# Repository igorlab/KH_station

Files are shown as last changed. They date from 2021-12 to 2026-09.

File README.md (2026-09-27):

# KH station




**An automatic KH tester for reef aquariums.** It takes a sample of tank water, titrates
it with acid on its own schedule, and sends the result to your Telegram. A live
dashboard runs in your browser, and every reading can also be logged to
[labaqua.net](https://labaqua.net/).

- Measures KH (carbonate hardness) by real titration to pH 4.10, no test kit or colour
  chart
- Runs on a schedule, rinses itself, and re-checks any result that looks off
- Controlled from Telegram, a web page on your network, or USB
- Updates its own firmware over Wi-Fi
- Open hardware: 3D-printed parts, ESP32 board, schematics and parts list in this repo

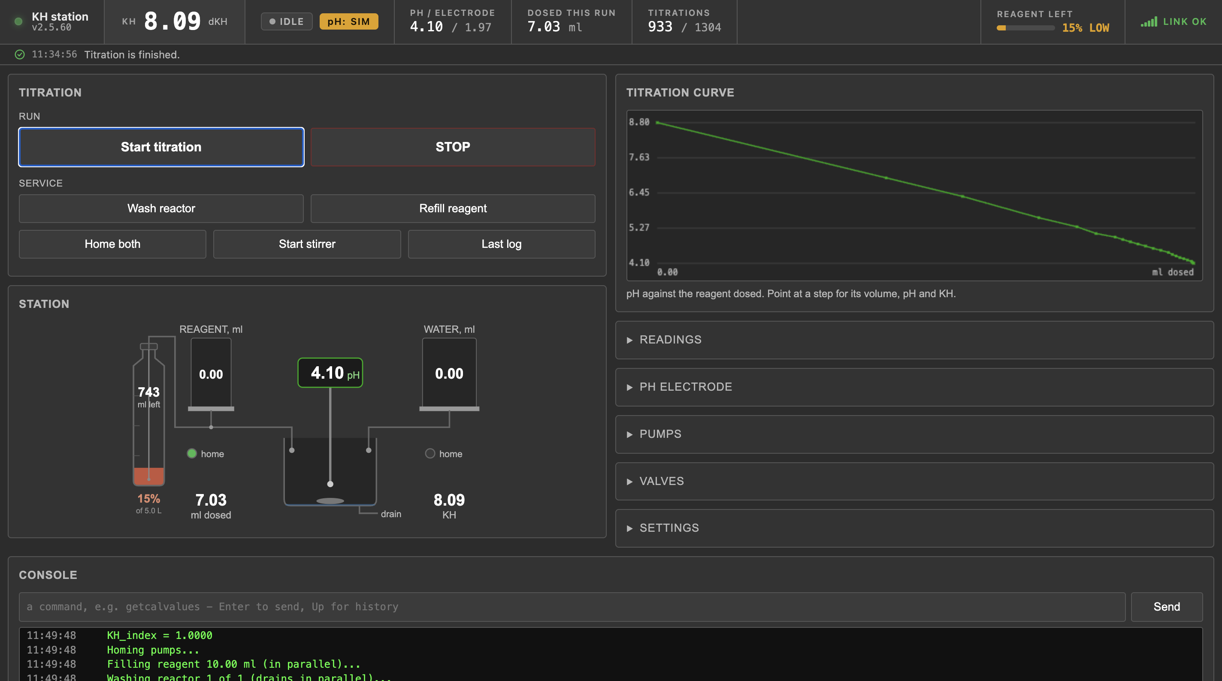
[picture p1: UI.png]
The KH station web dashboard
[](UI.png?raw=1)

*The web dashboard: latest KH, a live diagram of the station, the titration curve and
the console. Click for full size.*

<table>
<tr>
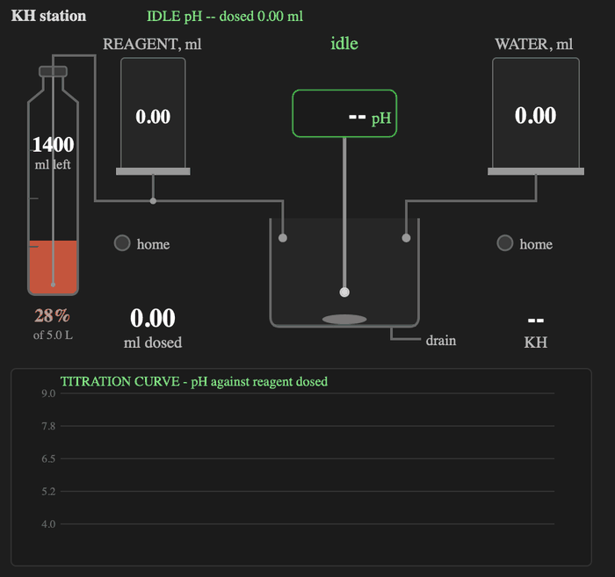
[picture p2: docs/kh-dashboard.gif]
A titration on the dashboard, start to finish
<td width="50%"></td>
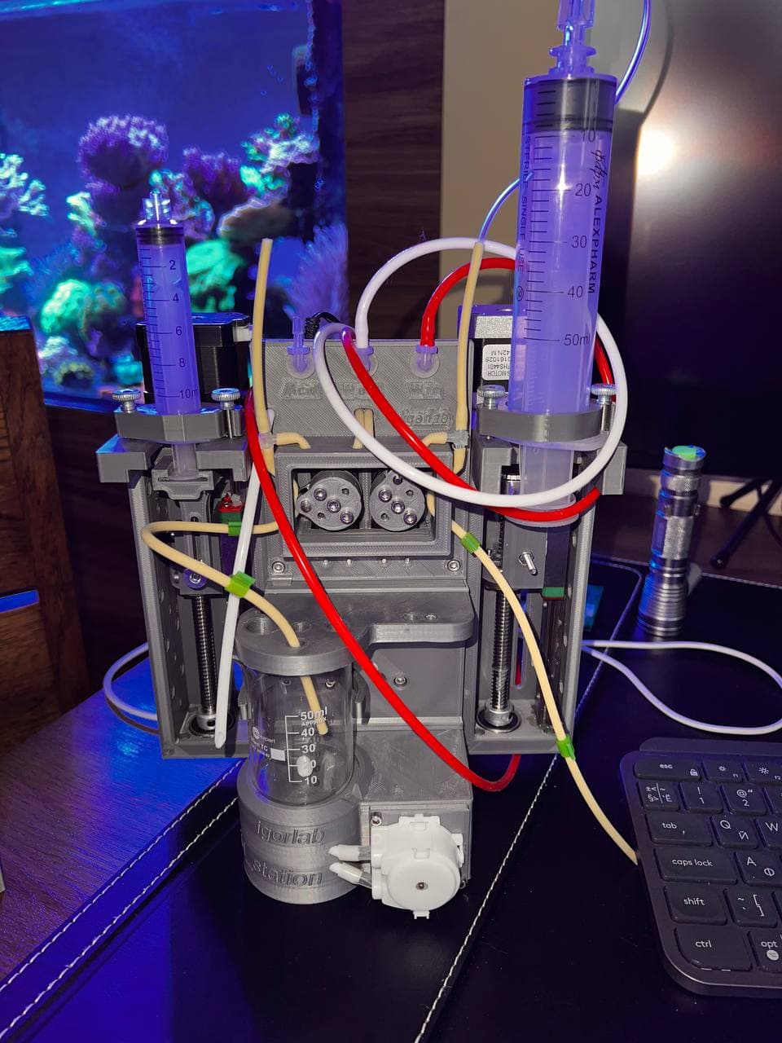
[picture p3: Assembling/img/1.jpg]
A built KH station next to a reef tank
<td width="50%"></td>
</tr>
<tr>
<td><em>One whole run on the dashboard, from rinse to result</em></td>
<td><em>A built station next to the tank</em></td>
</tr>
</table>

Build and demo video (https://youtu.be/T8ol2PM2Kjg)

Questions, feedback, or just want to see what other people are building? Join the
[Arduino Aquarium titrator group chat](https://t.me/+Ad4m-7L7tV1lNGNi).

**Contents:** [What it does](#what-it-does) ·
[Hardware](#hardware) ·
[Getting started](#getting-started) ·
[Web dashboard](#web-dashboard) ·
[Commands](#command-reference) ·
[Firmware updates](#firmware-updates) ·
[Building from source](#building-from-source)

---

## What it does

It runs a real titration — the same kind you'd do by hand with a syringe and a test kit
— except it does it by itself, on a timer, and tells you the number afterwards.

One run looks like this:

1. **Home** — both syringes move to their limit switches, so the machine knows exactly
   where they are before it starts.
2. **Draw reagent** — the reagent syringe pulls in 10 ml of HCl while the water side is
   busy with the next steps, so no time is wasted.
3. **Rinse** — the reactor gets flushed with tank water and drained, so nothing from the
   last test is left behind.
4. **Take a sample** — 25 ml of tank water goes into the reactor.
5. **Settle** — the stirrer runs for a bit so the electrode has time to give a steady
   reading.
6. **Dose** — acid goes in step by step, starting big (3 ml) and getting finer (down to
   0.01 ml) as the pH gets close to the endpoint. After each drop, it waits for the
   reading to actually settle instead of just waiting a fixed number of seconds.
7. **Endpoint** — dosing stops at **pH 4.10**.
8. **Wrap up** — both syringes go home, the reactor drains, and the result is sent out.

The math behind the number:

```
KH = (2804 × acid used, ml × acid concentration) / (sample size, ml / 1.026)
```

Defaults are 0.01 mol/L HCl and a 25 ml sample, both of which you can change.

If a result is more than `maxDeviation` (0.30 dKH by default) away from the last one,
the station doesn't just report it — it runs again to double-check. If two retries in a
row still don't agree, it tells you something's off instead of guessing.

---

## Hardware

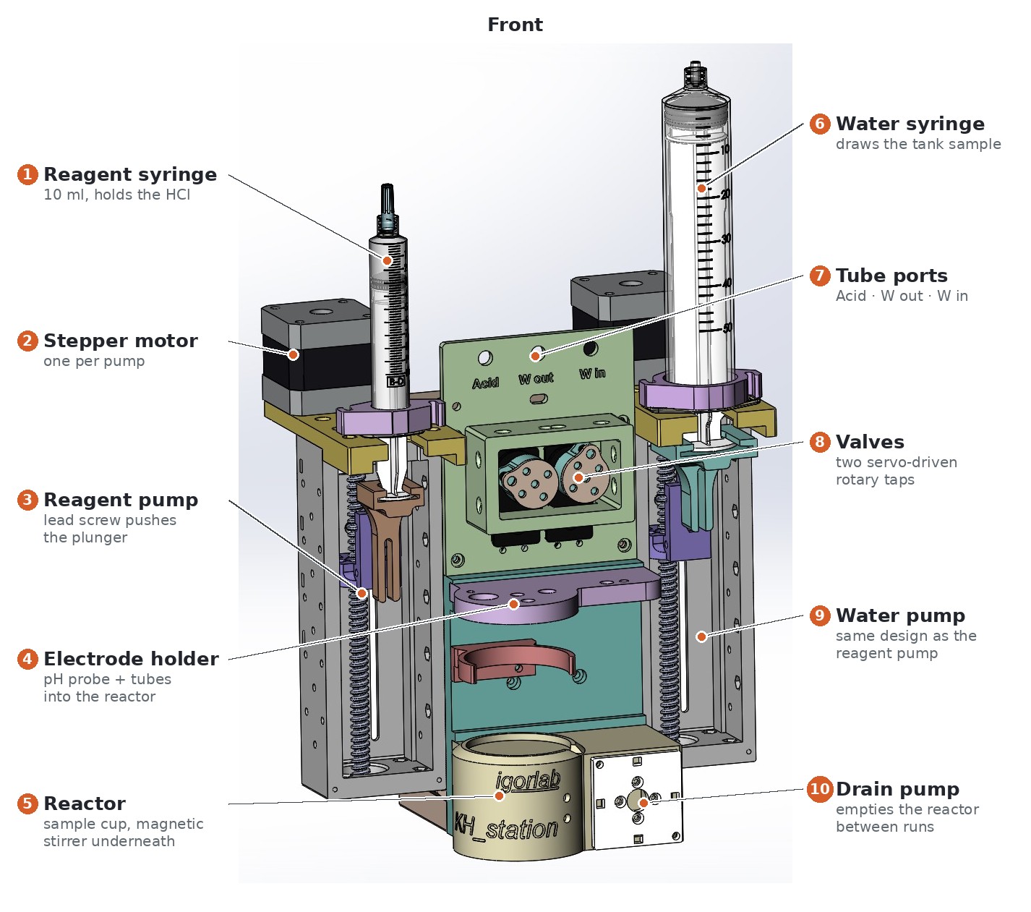
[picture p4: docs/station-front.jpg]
The station from the front, with its parts labelled


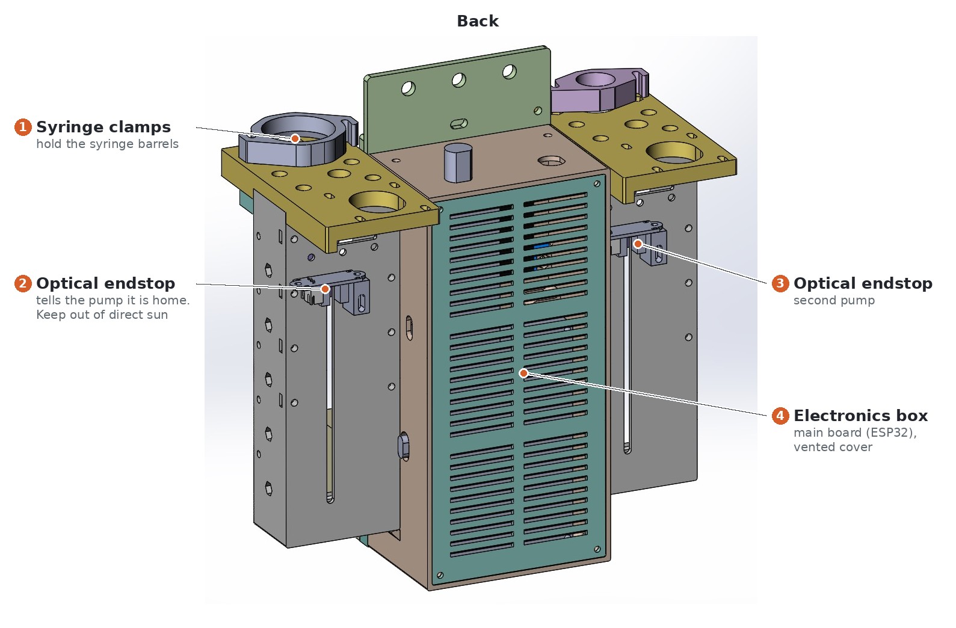
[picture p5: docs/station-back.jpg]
The station from the back, with its parts labelled


Full build guide with photos: [Assembling](Assembling/readme.md). Printed parts:
[STL](STL/). Board: [PCB](PCB/).

- **ESP32** (DOIT DEVKIT V1 or similar, 4 MB flash)
- **Two syringe pumps** — one for reagent (10 ml), one for the water sample (25 ml).
  Each has its own stepper motor, a limit switch for homing, and a small servo-driven
  valve that switches between filling and injecting.
- **pH electrode**, read through an amplifier board into the ESP32's ADC
- **Magnetic stirrer**
- **Drain pump** to empty the reactor between runs

Pin map (`include/PIN_definition.h`):

| Function | GPIO | | Function | GPIO |
|---|---|---|---|---|
| Reagent EN / STEP / DIR | 13 / 12 / 23 | | Water EN / STEP / DIR | 27 / 26 / 19 |
| Reagent endstop / valve | 16 / 18 | | Water endstop / valve | 5 / 17 |
| pH input | 35 | | pH loopback for bench testing | 25 |
| Drain pump | 33 | | Stirrer | 32 |
| Buzzer | 4 | | | |

### Pump speed

The two pumps don't all move at the same speed — on purpose:

| Move | Speed | Why it's set this way |
|---|---|---|
| Dosing | 1000 Hz | This is the number that becomes your KH result, so it moves carefully |
| Filling | 1500 Hz | Also matters for accuracy, but less critical, so a bit faster |
| Homing | 3000 Hz | Just driving to a limit switch, so it can go fast |

You can change any of these later (`setdosehz_`, `setfillhz_`, `sethomehz_`) if you've
tested your build at a higher speed and trust it.

### Keep the endstops out of the sun

The limit switches are **optical** (a light beam across a slot). Direct sunlight, or a
bright lamp shining into the slot, blinds them: the station then cannot tell that a
syringe has reached home, and homing fails or ends in an error. This has happened on a
real station. Place the station out of direct sun, or shade the endstops, keeping the
slot itself clear for the flag that moves through it.
If you see `Home can not be reached` or `endstop reads HOME but ... steps are still
loaded` in the console, check the light on the endstops first.

---

## Getting started

### 1. Set up the device

**Wi-Fi first.** On its first start the station opens its own Wi-Fi access point called
**AutoConnectAP**. Join it from your phone, pick your network and type its password —
the station remembers it and connects from then on. (It opens AutoConnectAP again
whenever it can't reach that network at startup — but since firmware 2.5.6 it no longer
waits there: it keeps titrating, looks for its network every minute and reconnects by
itself, so after a power cut it comes back even if the router starts slower than it.)

**Then Telegram.** You need a bot of your own and your numeric Telegram ID —
**[Setting up Telegram](docs/telegram-setup.md)** walks you through both in about five
minutes.

With those in hand, give it the rest — either on the page
`http://kh-station.local/settings` (linked at the bottom of the dashboard; it shows what
is already set), or over USB with a serial monitor at **115200 baud**,
one line at a time:

```
bottoken_<the token @BotFather gave you>
settlgrmid_<your numeric Telegram id>
ukey_<the token labaqua.net emailed you>
```

`ukey_` restarts the station, so send it last. Don't skip `settlgrmid_` — it's what
keeps strangers from being able to control your station over Telegram. If everything
went through, the bot will say "KH station started" once it restarts. Since firmware
2.5.13 that message also says **why** the station restarted — power cut, a dip in the
power supply, a crash or a command — and `lastreset` repeats it. If your station keeps
restarting on its own, that line is the thing to send when you ask for help. Bot
silent? See [If the bot stays silent](docs/telegram-setup.md#if-the-bot-stays-silent).

**Optional: a backup Wi-Fi network** (firmware 2.5.4 and newer). If the main network is
unreachable for a minute, the station joins the backup by itself and tells you in
Telegram. Set it on the `/settings` page, or with
`wifibackup_<network name>#<password>`. `wifibackup` shows which network it is on,
`wifiswitch` changes over by hand.

### 2. Calibrate the pumps

This is the step that matters most for accuracy, so it's worth doing properly before you
trust any reading.

1. In Telegram: **Calibrations** → **Calibrate pumps**
2. Put the tube over a cup on a scale and run **Run \<pump\> pump test**
3. When it beeps three times, weigh what came out
4. Not quite right? Send the real weight back with **Set real \<pump\> mass**, e.g. `24.87`
5. Repeat until it's spot on

Target: **reagent 10.00 ± 0.05 g, water 25.00 ± 0.05 g.**

### 3. Calibrate the pH electrode

The station ships with a placeholder calibration — you'll want to set your own with two
buffer solutions, 4.01 and 6.86:

1. Rinse the electrode and put it in the 4.01 buffer
2. Press **Start reading pH** (web) or send `readph` (serial), and wait for the number
   to stop moving
3. Send `calph_4.01`
4. Rinse, switch to the 6.86 buffer, and send `calph_6.86`

Don't skip the "wait for it to settle" part in step 2 — calibrating on a reading that
hasn't stabilized yet locks in a slightly wrong number, and every KH result after that
inherits the error.

---

## Web dashboard

Just open `http://<device-ip>/` — or `http://kh-station.local/` — nothing to install, no
internet connection needed.

(Screenshots are [at the top](#kh-station).)

The bottle on the left is your reagent stock — the level drops as it gets used, and it
tells you how many millilitres are left. The stir bar moves while the stirrer is
running, and the two `home` lamps are the syringe limit switches: green when a syringe
is parked, dark when it is not, amber if the switch cannot make up its mind.

- **Header** — the latest KH, what the station is doing, and on the right the firmware
  version, the Wi-Fi network (orange when it's the backup) and its signal as 0–5 bars
- **Station diagram** — both syringes, the reactor, the tubing, the stirrer, plus the
  numbers you actually care about: pH, KH, ml dosed
- **Titration curve** — pH plotted against volume as it doses, so you can see the shape
  of the run; between runs it just plots pH over time
- **Console** — a live feed of what the station is doing, not a stale snapshot
- **Readings** — every stored value, including the correction index and how much
  reagent you have left
- **Pumps / Settings** — tucked away since you'll rarely need them day to day

Every button asks for confirmation before it actually moves anything.

> There's no login on the dashboard. Keep the station on a network you trust, and don't
> expose it to the internet.

---

## Command reference

These work the same way over serial, Telegram, and
`http://<device-ip>/commands?param=<command>`. Anything marked ⚠ moves hardware and
won't run while a titration is in progress.

**Titration**

| Command | What it does |
|---|---|
| `titr_1` ⚠ | Start a titration right now |
| `stoptitr` | Stop the current run; both syringes return home |
| `washreactor` ⚠ | Rinse and drain the reactor |
| `refilreagent` ⚠ | Top up the reagent line |
| `allhome` ⚠ | Send both syringes home |
| `lastkh`, `counttitr`, `lastlog` | Last result, run count, log from the last run |

**pH**

| Command | What it does |
|---|---|
| `readph` / `stopreadph` | Start / stop live reading |
| `calph_4.01`, `calph_6.86` | Save a calibration point |
| `phwait_<ms>_<eps>_<n>_<timeout>` | Tune how the station decides a reading has settled |
| `phfilter_<mea>_<est>_<q>` | Advanced: filter tuning — changes the measured pH itself |
| `phsim_1` / `phsim_0` | Use a simulated reading instead of the real electrode — until the next restart; the station always starts on the real electrode (firmware 2.5.15 and newer) |
| `phloop_1` / `phloop_0` | Bench-test mode without a probe at all (see below) |

**Settings**

| Command | Default |
|---|---|
| `maxdeviation_<dKH>` | 0.30 |
| `retitrhour_<1..24>` | 3 |
| `setwvolume_<ml>` | 25.00 |
| `setrvolume_<L>` | 5.0 (reagent stock) |
| `setdosehz_` / `setfillhz_` / `sethomehz_` | 1000 / 1500 / 3000 |
| `stirrerd_<0..255>` | 220 |
| `settings`, `getcalvalues` | Show everything that's currently stored |

**System**

`restart`, `getip`, `freeheap`, `gettime`, `checkupdate`, `updatedevice`, `sendlogs`

---

## Firmware updates

The station checks `firmware/bin_version.txt` in this repo, and if there's a newer
version, it'll offer to update from the Telegram **Update** menu. Sending
`updatedevice` downloads `firmware/firmware.bin` over a secure connection and installs
it — no cable needed.

---

## Upgrading a station that's been running for a long time

**If your station is still on firmware 2.2.x, read this before updating.**

Older firmware saved a few settings (your sample size, last result, reagent used so
far) under different internal names than the current firmware looks for. Update
straight over the air and those won't carry over — the station will quietly reset them
to factory defaults instead of telling you anything changed.

`tools/kh_loader/kh_loader.ino` fixes this for you. Flash it once from the Arduino IDE
and it will:

1. **Print out everything** currently stored, so you have a record
2. **Carry over** your old settings to where the new firmware expects them
3. **Connect to Wi-Fi and install the latest firmware**

Your pump and pH calibration are untouched either way — no need to redo those.

It's safe to run more than once: it only ever fills in a setting that's missing. If
both an old and a new copy of a setting already exist, it leaves both alone and just
shows you what it found.

What to set in the Arduino IDE first (the second one trips people up):

- **Board** → ESP32 Dev Module
- **Partition Scheme** → *Minimal SPIFFS (1.9MB APP with OTA/128KB SPIFFS)* — the
  default scheme doesn't leave enough room and the install will fail right at the end
- **Upload Speed** → 115200
- **Erase All Flash Before Sketch Upload** → *Disabled* — otherwise the upload itself
  wipes the calibration this sketch exists to keep

It connects to the Wi-Fi network your station already uses, so there is usually
nothing to type into the sketch. To use a different network, fill in `WIFI_SSID` and
`WIFI_PASS` at the top.

Already on 2.3 or newer? You can just update normally from Telegram.

---

## Repository layout

| Path | What's in it |
|---|---|
| `firmware/` | `firmware.bin` and `bin_version.txt` — what your station downloads when it updates itself |
| `PCB/` | schematics (main board and pH front end) and the parts list |
| `STL/` | every 3D-printed part: pump bodies, carriage, reactor holder, valve rotors, stirrer |
| `Assembling/` | build photos and notes |
| `docs/` | step-by-step guides — [creating your Telegram bot and finding your ID](docs/telegram-setup.md) |
| `tools/kh_loader/` | a small helper sketch for upgrading an older station (see [Upgrading](#upgrading-a-station-thats-been-running-for-a-long-time)) |
| `tools/readme_images/` | the script that draws the labelled station pictures in `docs/` |

---

## Building from source

```bash
pio run                 # build
pio run -t upload       # flash over USB
```

`platformio.ini` points at a specific fork of the ESP32 platform:

```ini
platform = https://github.com/pioarduino/platform-espressif32.git#55.03.311
```

That's intentional — the mainstream platform hasn't caught up to the newer Arduino
core yet, so this project uses the [pioarduino](https://github.com/pioarduino/platform-espressif32)
fork instead, pinned to an exact version so a future update can't change the build
under you.

**Upload speed needs to stay at 115200** — faster speeds don't work reliably with this
board and cable combination.

Nothing secret lives in this repository. Your Wi-Fi password, Telegram token, chat ID
and labaqua key are all stored on the device itself, set with the commands above —
never in the source code.

---

## Testing without a pH probe connected

Send `phloop_1` and the ESP32 will simulate an electrode for you: it generates a
voltage internally and reads it back, so everything downstream — filtering,
calibration, the math — runs exactly as it would with a real probe. You'll need a
jumper wire from **GPIO25 to GPIO35** for this to work; if it doesn't detect one, it'll
tell you.

It's meant for testing only and is never saved — every restart goes back to the real
electrode, so you can't accidentally leave a station running on fake readings.

---

## Built-in safety checks

- **Won't dose into a sample that looks wrong.** If the starting pH doesn't look like
  water — say, the probe isn't actually connected — it stops and tells you, instead of
  quietly reporting a KH of 0.00.
- **Won't report a run that used zero reagent.** That's never a real result.
- **Won't publish a number it doesn't trust.** If a result disagrees with the last one,
  it retries; after two disagreements in a row, it tells you rather than guessing.
- **Always returns home after a stop.** Hit `stoptitr` and both syringes go back to a
  known position — nothing is left loaded or half-moved.

---

## License

GPL-3.0. See [LICENSE](LICENSE).

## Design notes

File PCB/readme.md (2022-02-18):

# PCB

R SMD 0603
C SMD 0603

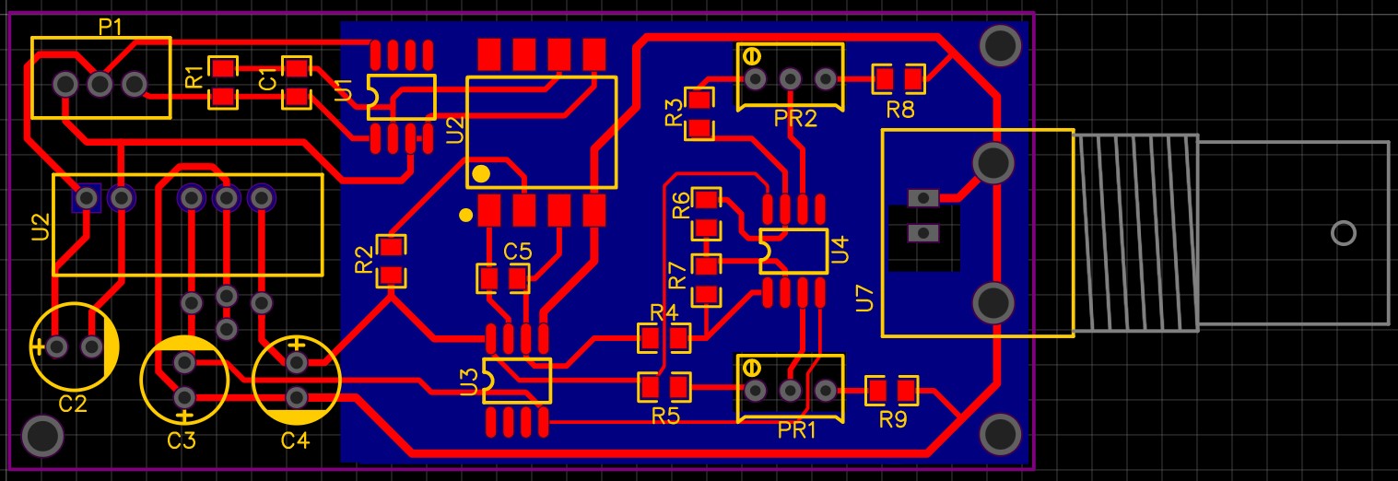
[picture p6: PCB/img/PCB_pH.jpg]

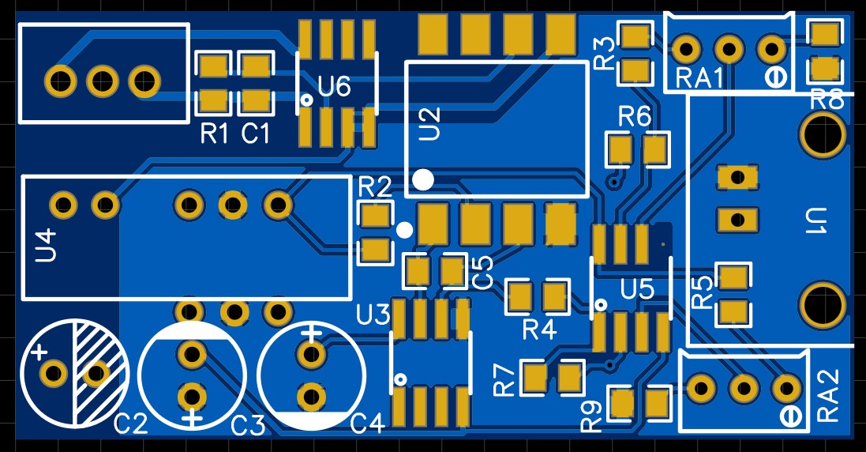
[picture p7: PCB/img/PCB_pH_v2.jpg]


All parts

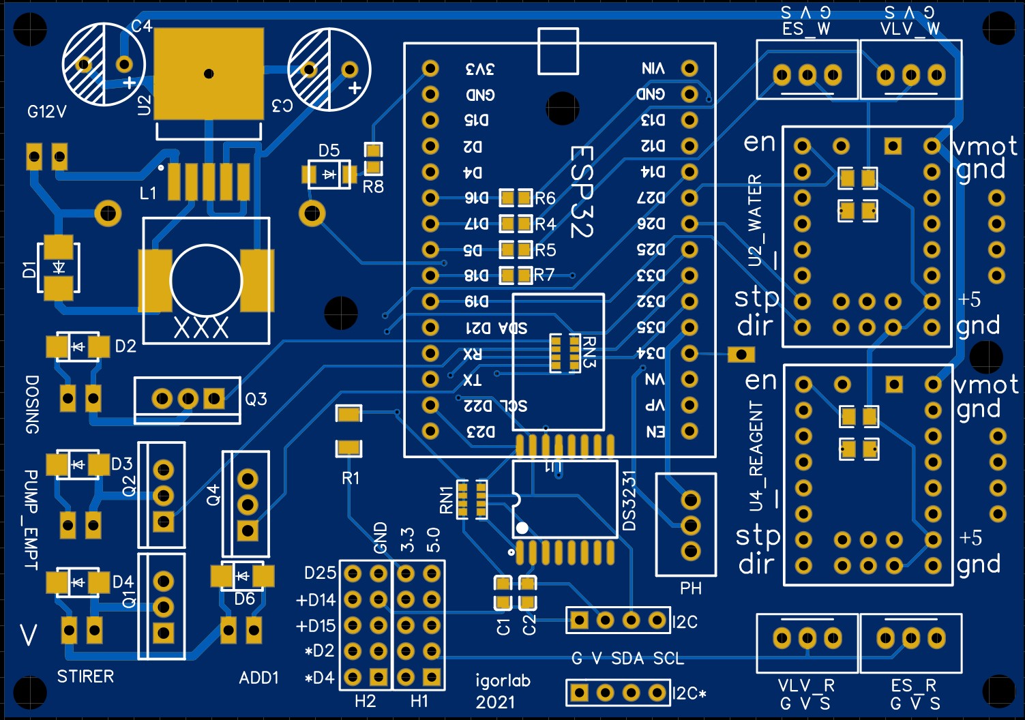
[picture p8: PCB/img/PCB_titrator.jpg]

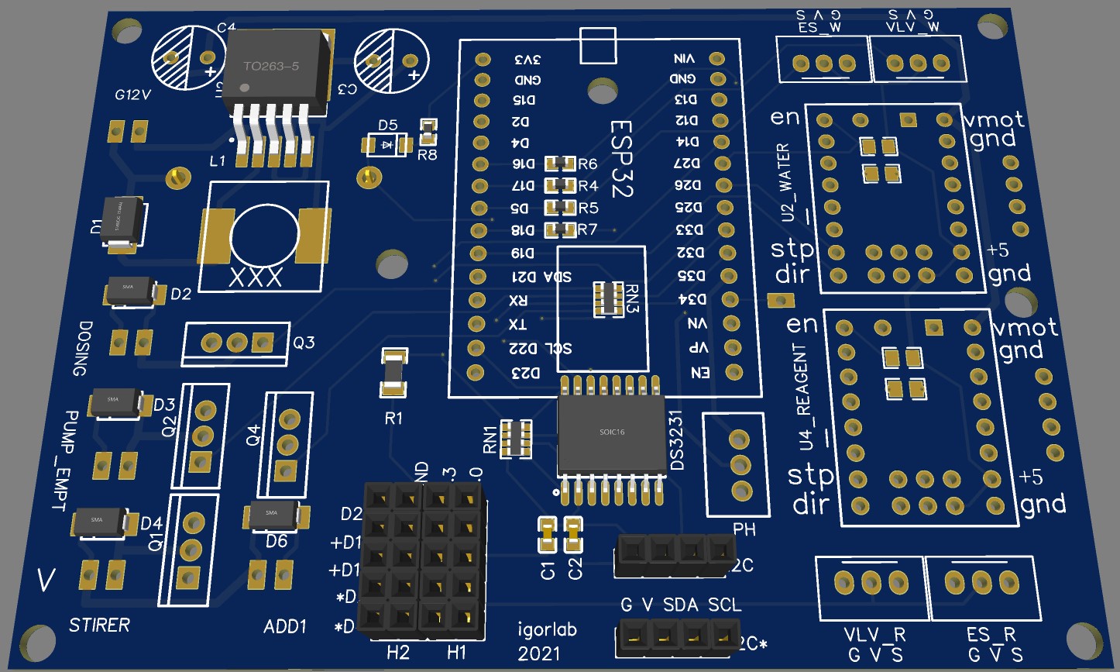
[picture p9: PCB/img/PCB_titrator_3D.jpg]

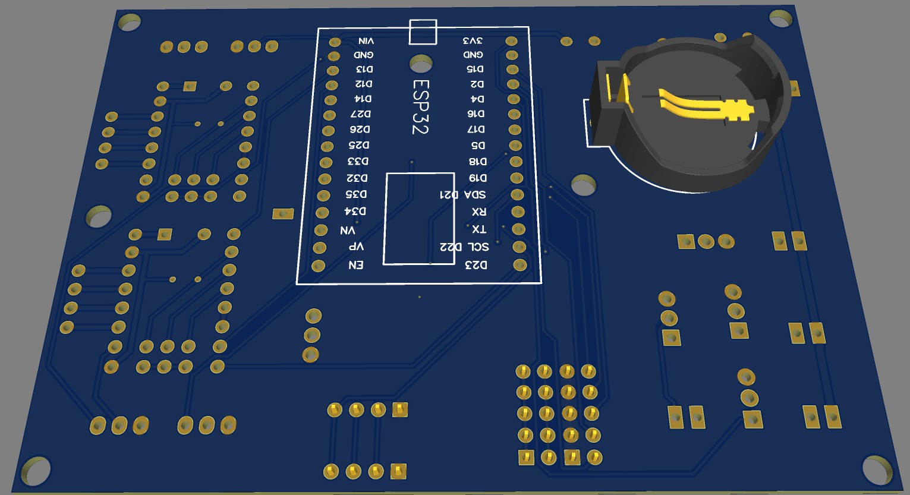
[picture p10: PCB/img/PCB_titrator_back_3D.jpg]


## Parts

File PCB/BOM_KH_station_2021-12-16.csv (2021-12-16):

ID | Name | Designator | Footprint | Quantity | Manufacturer Part | Manufacturer | Supplier | Supplier Part | Price | SMT Type | image | link
1 | XHP-2 | ADD1,DOSING,G12V,PUMP_EMPT,STIRER | JST_XHP-2 | 5 | ?
2 | CR2032 | B1 | BAT-TH_BS-2-1 | 1 | BS-2-1 | Q&J | LCSC | C70376 | 0.064 |  | //image.lceda.cn/szlcsc/C70376.jpg
3 | 1u | C1 | C0603 | 1
4 | 100n | C2 | C0603 | 1
5 | 1000uF | C3 | CAP-8*5 | 1 | 1000uF 16V | ReliaPro | LCSC | C13376 | 0.032
6 | 100uF | C4 | CAP-8*5 | 1 | 100uF 25V | ReliaPro | LCSC | C13376 | 0.032
7 | SS34B | D1 | SMB_L4.6-W3.6-LS5.3-RD | 1 | SS34B | Jingdao | LCSC | C169415 | 0.062 | Extend
8 | SS34A | D2,D3,D4,D6 | SMA_L4.3-W2.6-LS5.2-RD | 4 | SS34A | Yangzhou Yangjie Elec Tech | LCSC | C211775 | 0.053
9 | 1N4004F | D5 | SMAF | 1 | 1N4004F | SK | LCSC | C122842 | 0.01
10 | DS3231 | DS3231 | SOIC-16_L10.3-W7.5-P1.27-LS10.3-BL | 1 | DS3231SN | MAXIM | LCSC | C9866 | 14.666 |  | http://image.lceda.cn/szlcsc/C9866.jpg
11 | B3B-XH-A-LF-SN | ES_R,ES_W,VLV_R,VLV_W | B3B-XH-A-LF-SN | 4 |  |  | LCSC | C144394 | 0.042
12 | HDR-F-2.54_2x5 | H1,H2 | HDR-F-2.54_2X5 | 2 |  |  | LCSC | C30419
13 | HDR-F-2.54_1x4 | I2C,I2C* | HDR-F-2.54_1X4 | 2 |  |  | LCSC | C225501 | 0.074
14 | 470uH | L1 | 12.3X12.3X8.0 | 1 | SMDRI127-471MT | SXN | LCSC | C10153 | 0.199
15 | XH-3A | PH | XH-3A | 1 | XH-3A | BOOMELE | LCSC | C2316 | 0.007 |  | //image.lceda.cn/szlcsc/C2316.jpg
16 | TIP120 | Q1,Q2,Q3,Q4 | TO-220 | 4 | TIP120 | STMicroelectronics | LCSC | C262990 | 0.79
17 | 1k | R1 | R1206 | 1
18 | 1k | R4,R5,R6,R7 | R0603 | 4
19 | 200 | R8 | R0603 | 1
20 | 4.7K | RN1 | RES-ARRAY-SMD_0603-8P-L3.2-W1.6-BL | 1 | 4D03WGJ0472T5E | UniOhm | LCSC | C1980 | 0.006 | Basic
21 | 2K | RN3 | RES-ARRAY-SMD_0603-8P-L3.2-W1.6-BL | 1 | 4D03WGJ0472T5E | UniOhm | LCSC | C1980 | 0.006 | Basic
22 | ESP32_DOIT_V1_IL | U1 | ESP32_DOIT_V1_IL | 1 | ?
23 | LM2596S-5.0/TR | U2 | TO-263-5_L10.6-W9.6-P1.70-LS15.9-TL | 1 | LM2596S-5.0/TR | HGSEMI | LCSC | C194349 | 0.866 | Extend
24 | DRV8825_IL | U2_WATER,U4_REAGENT | DRV8825_IL-2 | 2 | ?

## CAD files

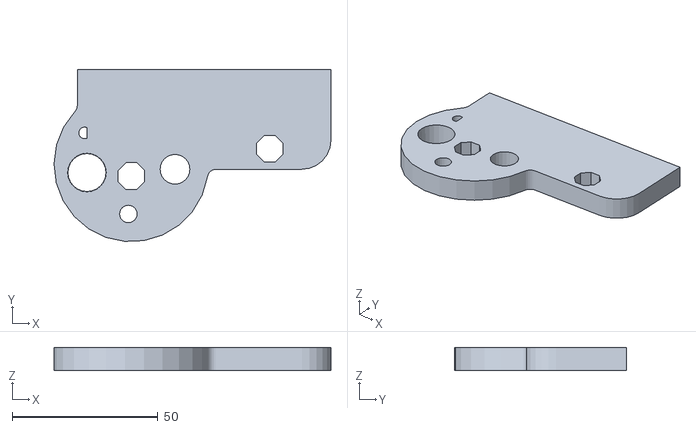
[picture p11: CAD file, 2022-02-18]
STL/pH_tube_holder.STL
95.0 x 58.9 x 8.00

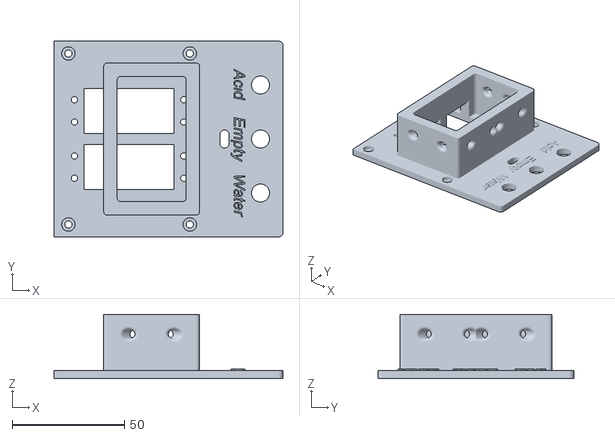
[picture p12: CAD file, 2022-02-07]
STL/FlowSwitcher.STL
101.8 x 87.0 x 28.6

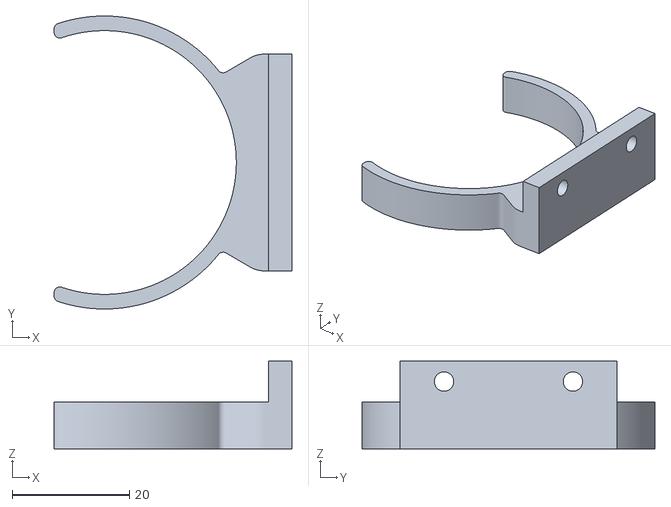
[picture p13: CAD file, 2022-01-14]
STL/reactor_holder.STL
40.6 x 50.0 x 15.0

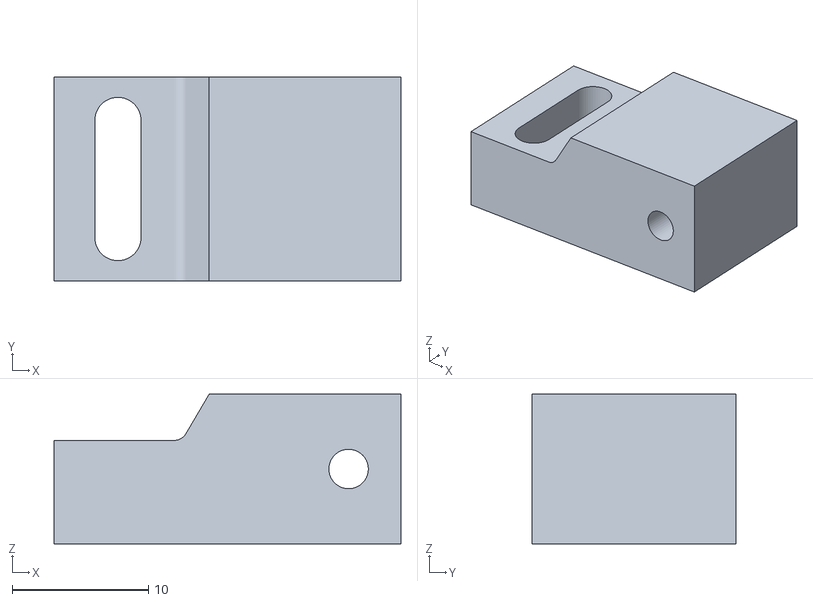
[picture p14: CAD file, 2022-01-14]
STL/Lerdge Optical Endstop MOUNT_v3.STL
25.5 x 15.0 x 11.0

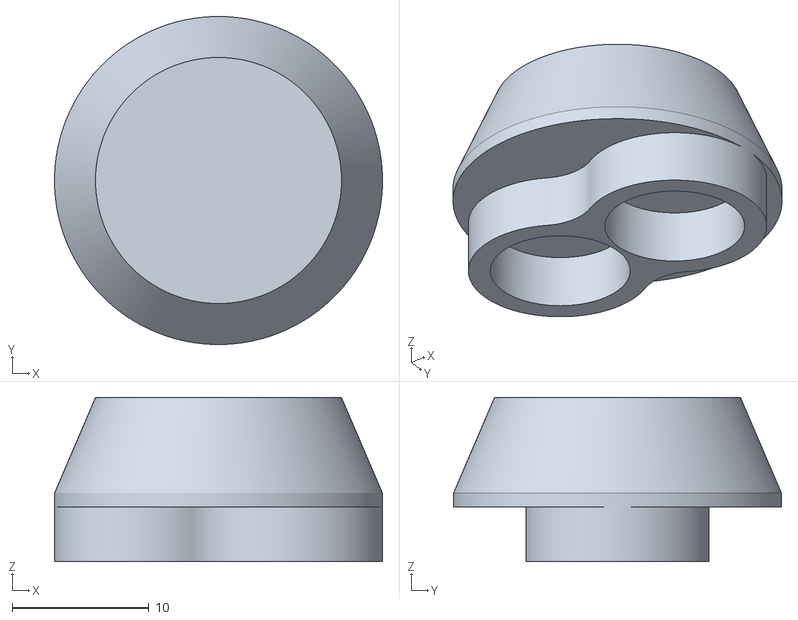
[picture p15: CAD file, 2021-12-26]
STL/stirrer_magnet.STL
24.0 x 24.0 x 12.0

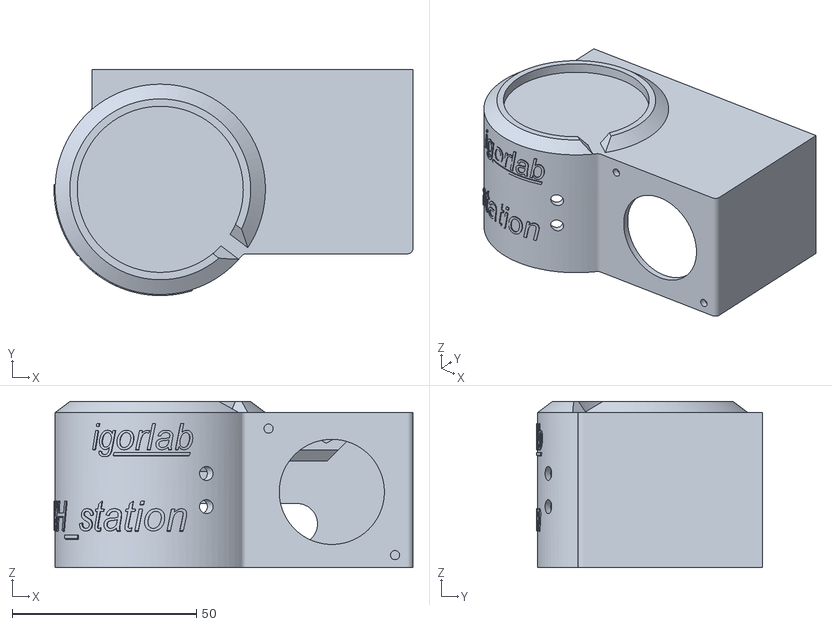
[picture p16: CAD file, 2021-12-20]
STL/base_stirrer_empty.STL
97.3 x 61.3 x 45.0

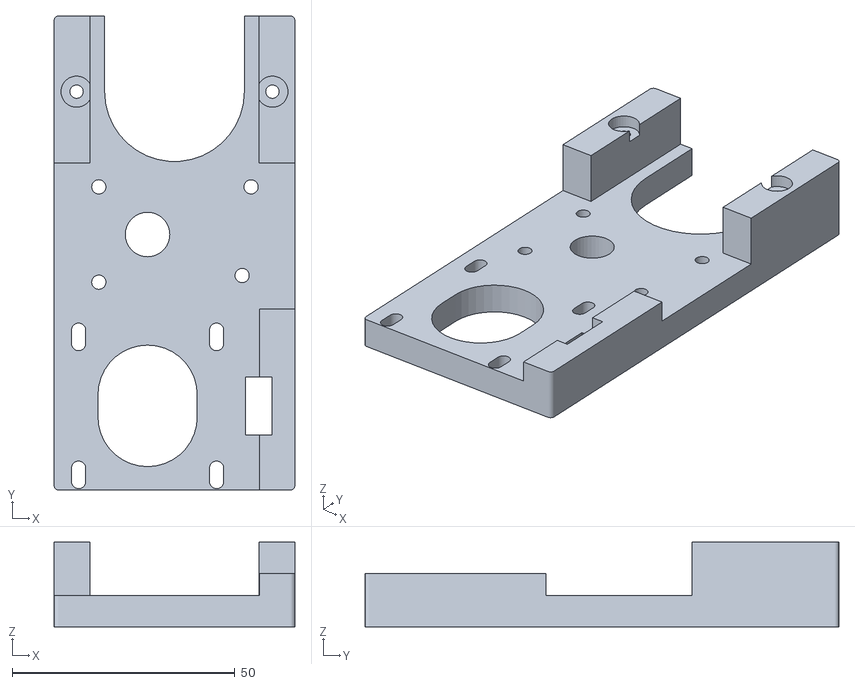
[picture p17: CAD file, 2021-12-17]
STL/motor_mount_plate_50ml.STL
54.1 x 106.5 x 19.0

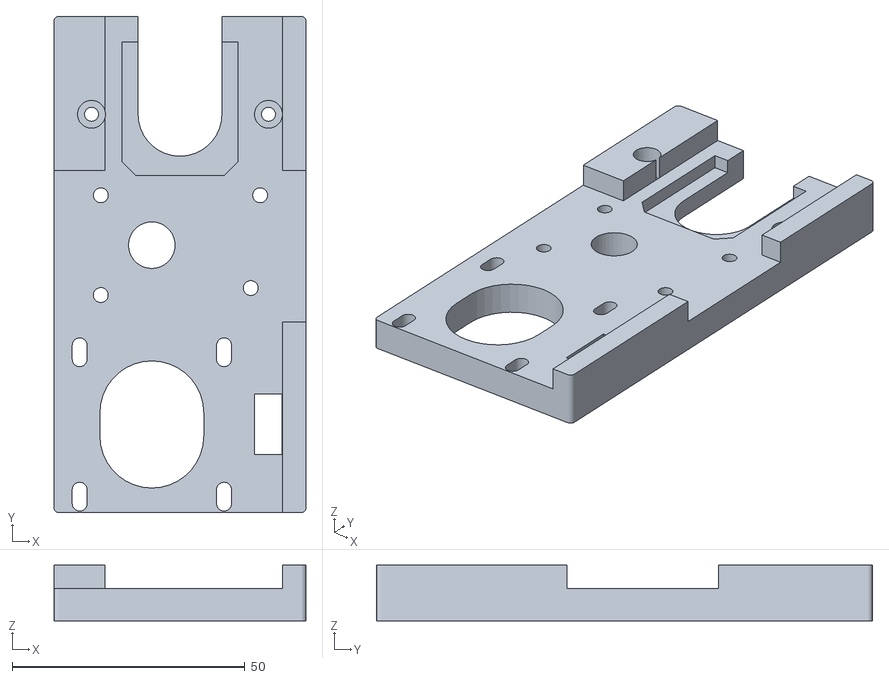
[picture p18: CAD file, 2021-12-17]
STL/motor_mount_plate.STL
54.1 x 106.5 x 12.0

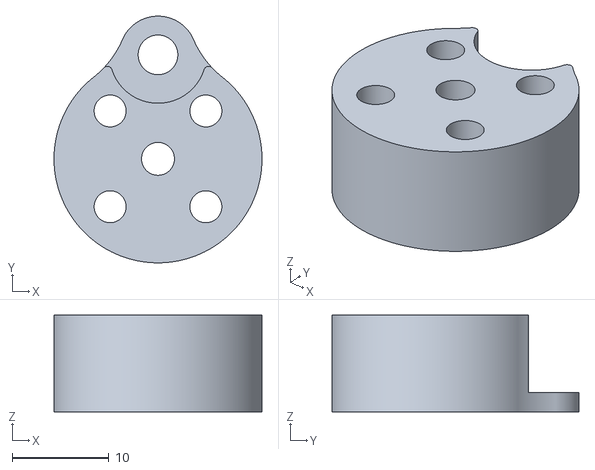
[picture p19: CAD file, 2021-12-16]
STL/tap_rotor_top_v2.STL
21.5 x 25.5 x 10.0

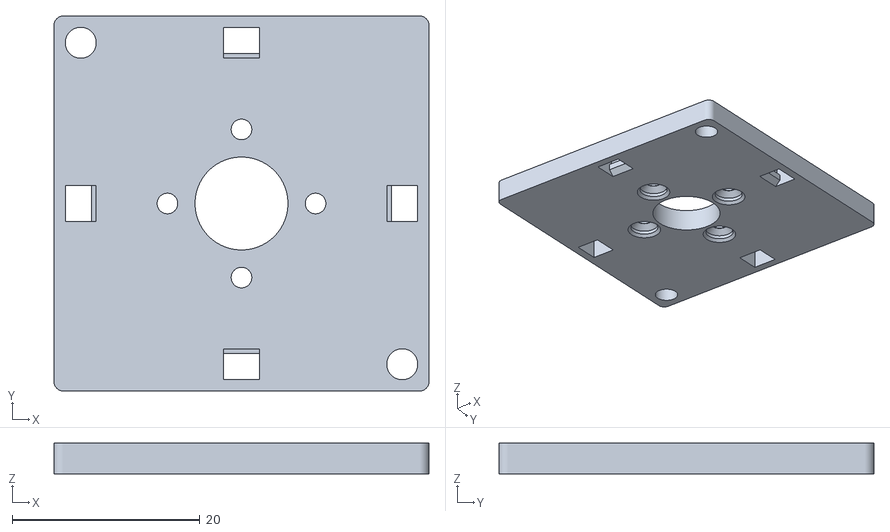
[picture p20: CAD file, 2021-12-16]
STL/empty_pump_mount.STL
40.0 x 40.0 x 3.30

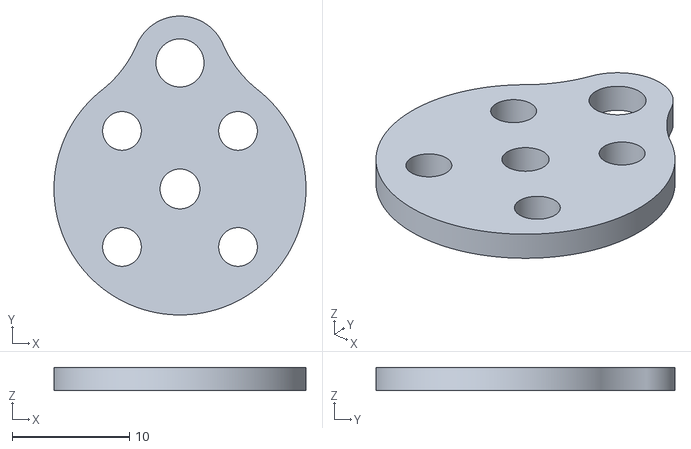
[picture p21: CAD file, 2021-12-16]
STL/tap_rotor_base_v2.STL
21.5 x 25.5 x 2.00

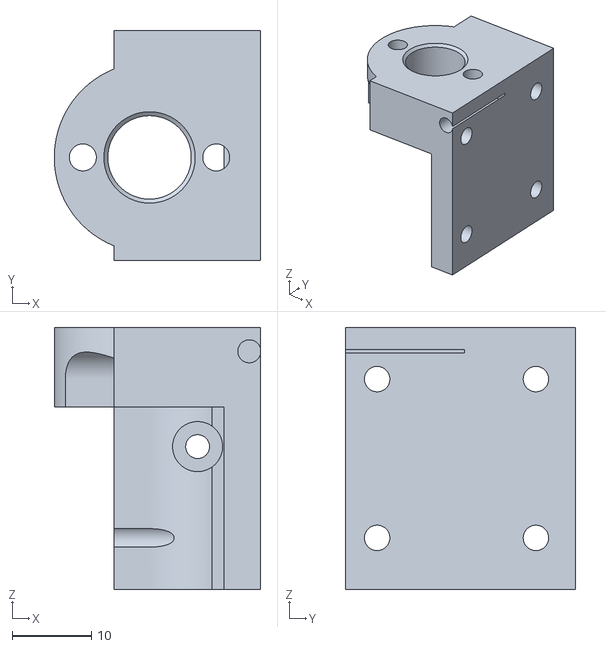
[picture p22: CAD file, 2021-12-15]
STL/carriage.STL
26.0 x 29.0 x 33.0

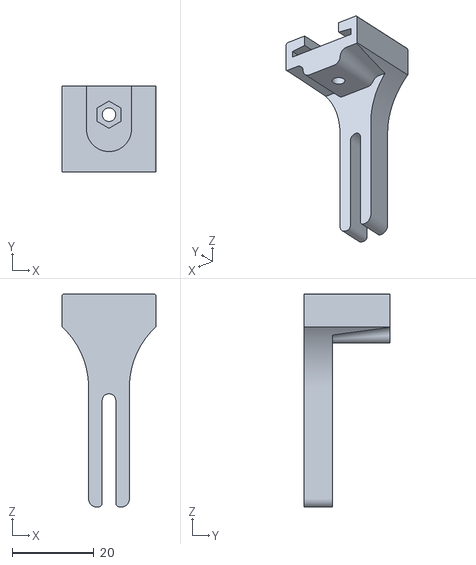
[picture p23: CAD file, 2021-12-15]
STL/syringe_plunger_retainer.STL
23.0 x 21.0 x 52.0

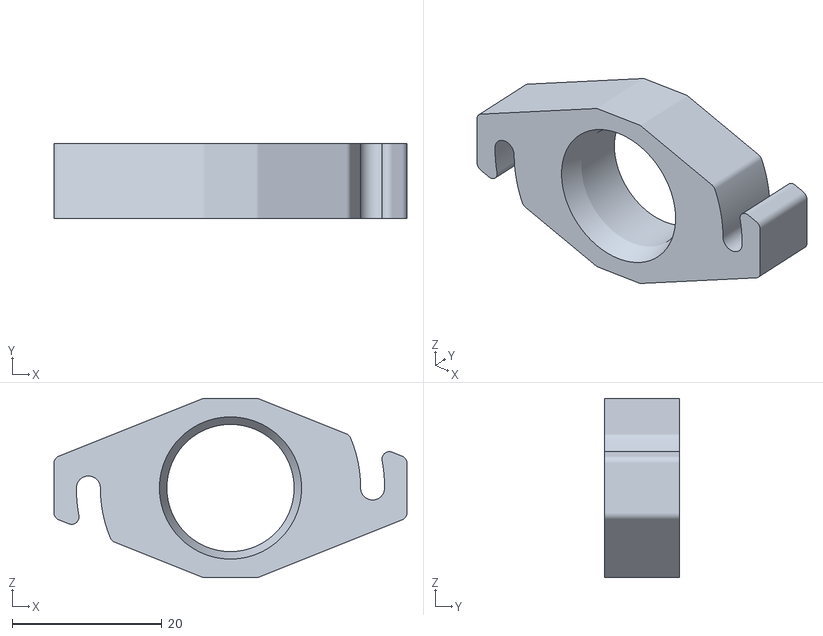
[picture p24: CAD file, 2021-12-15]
STL/syringe_retainer.STL
47.2 x 10.0 x 24.0

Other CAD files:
STL/syringe_retainer_50ml.STL
STL/lerdge_optical_endstop_mount_v2.STL

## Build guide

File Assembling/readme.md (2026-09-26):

# Autosampling titrator for aquarium

## Assembling guide
## 1. Syringe pump parts

Parts should be printed:

| # |Part name | Infill | Amount | Comment |
|---- |--- | --- | ---| ---|
| 1 |_syringe_pump_body.STL_ | 70 %  | 2 |
| 2 |_carriage.STL_ | 80 %  | 2
| 3  |_motor_mount_plate.STL_ | 80 %  | 1
| 4  |_motor_mount_plate_50ml.STL_ | 80 %  | 1
| 5  |_syringe_plunger_retainer.STL_ | 80 %  | 1
| 6  |_syringe_plunger_retainer_50ml.STL_ | 90 %  | 1
| 7  |_syringe_retainer.STL_ | 90 %  | 1
| 8  |_syringe_retainer_50ml.STL_ | 90 %  | 1
| 9  |_lerdge_optical_endstop_mount_v2.STL_ | 40 %  | 1

Another parts:

| # |Part name | Pcs | Length | Comment |
|---- |--- | --- | ---| ---|
| 1 |[_T8 Lead Screw_](https://aliexpi.com/KmXX) | 2  | 150 mm | Lead 2mm|
| 2 |[_Linear guide MGN12H_](https://shorturl.at/clrG2) | 2  | 125 mm
| 3 |[_GT2 Pulley 16T-5B_](https://www.aliexpress.com/item/32724156349.html?spm=a2g0s.9042311.0.0.27424c4dbSUZ1x) | 2  | 
| 4 |[_GT2 Pulley 20T-5B_](https://www.aliexpress.com/item/32724156349.html?spm=a2g0s.9042311.0.0.27424c4dbSUZ1x) | 2  | 
| 5 |[_GT2 Closed Loop Belt_](https://www.aliexpress.com/item/32950422029.html?spm=a2g0s.9042311.0.0.27424c4dVVutuE) | 2  | 
| 6 |[_Lock ring 8-14-8_](https://www.aliexpress.com/item/32826054805.html?spm=a2g0s.9042311.0.0.27424c4dj0xusA) | 2  | 
| 7 |[_LERDGE Optical Endstop_](https://www.aliexpress.com/item/32817734162.html?spm=a2g0s.9042311.0.0.27424c4d7GGfeK)  | 2  | 
| 8 |_Bolt m3_ | 4  | 30 mm
| 8 |_Bolt m3_ | 6  | 22 mm
| 8 |[_Bearing 608RS_](https://www.aliexpress.com/item/32888140495.html?spm=a2g0s.9042311.0.0.22244c4dhQX6c2) | 4  

>Step by step assembling

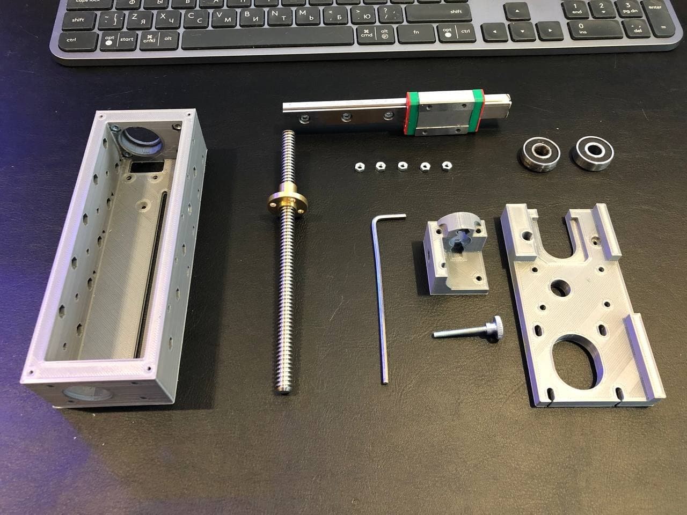
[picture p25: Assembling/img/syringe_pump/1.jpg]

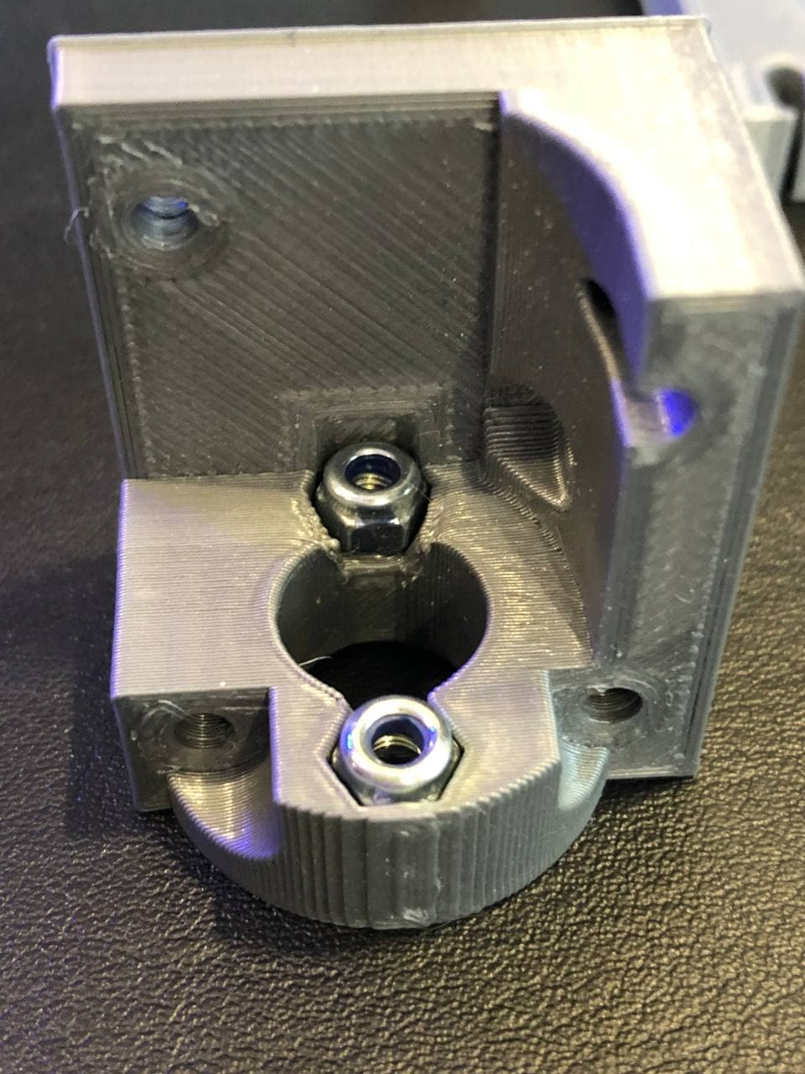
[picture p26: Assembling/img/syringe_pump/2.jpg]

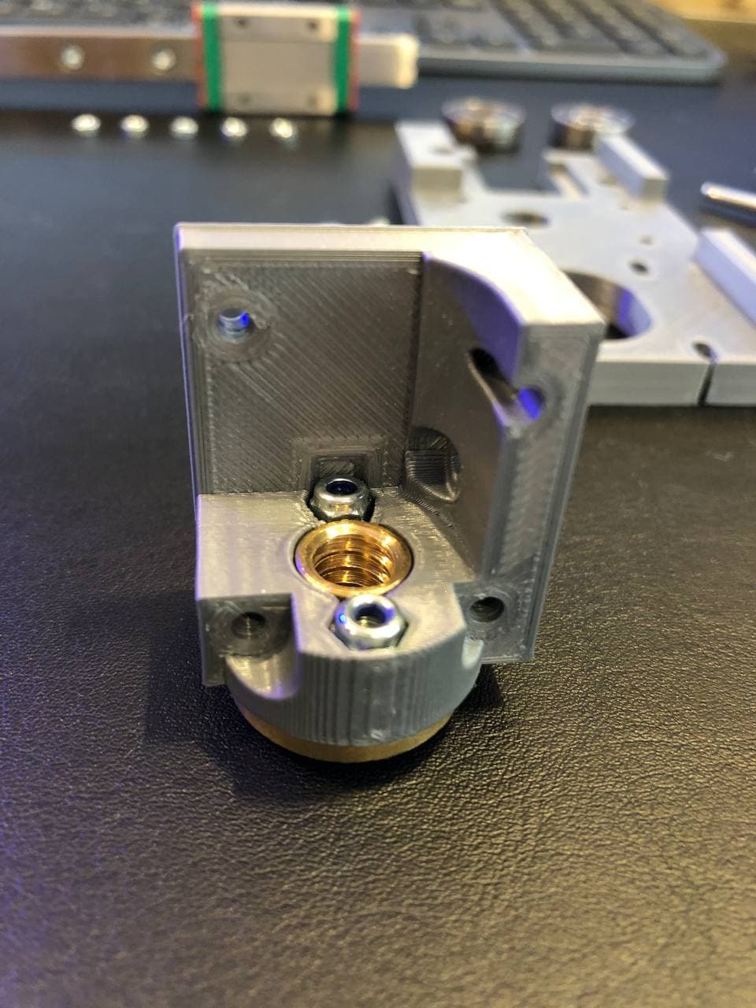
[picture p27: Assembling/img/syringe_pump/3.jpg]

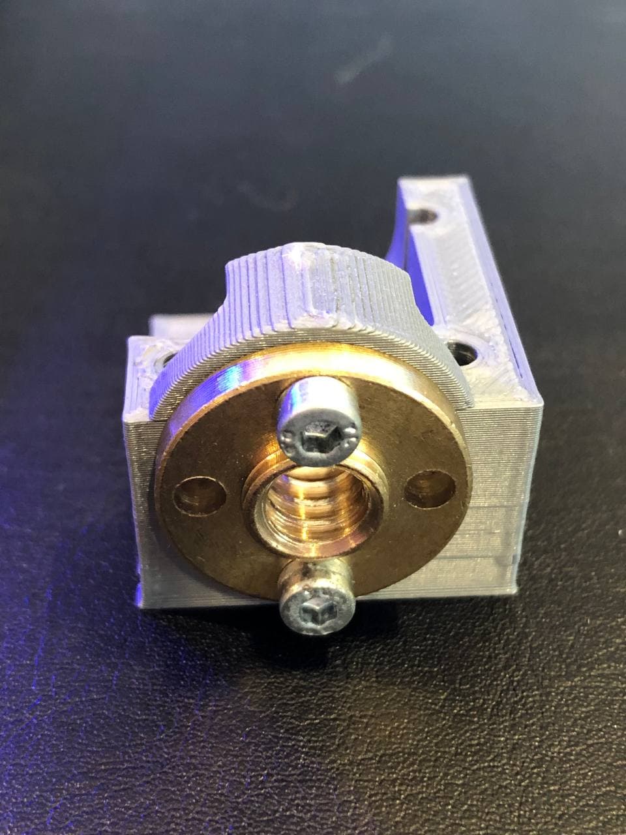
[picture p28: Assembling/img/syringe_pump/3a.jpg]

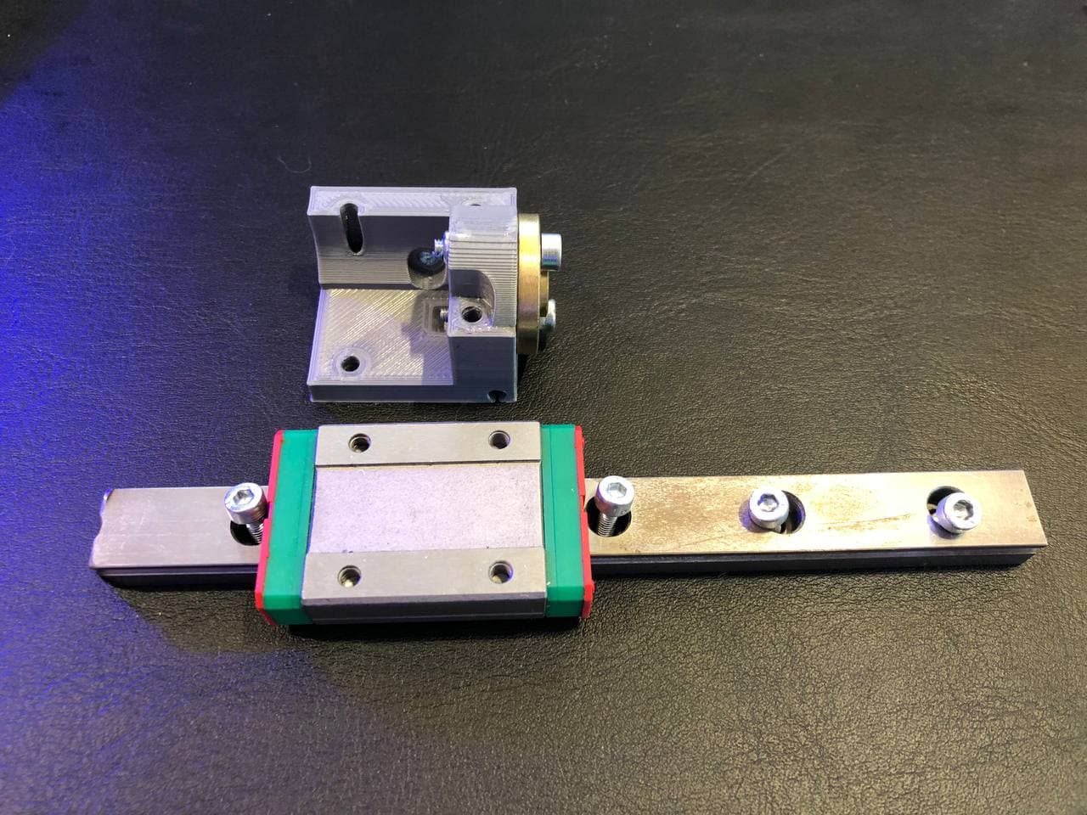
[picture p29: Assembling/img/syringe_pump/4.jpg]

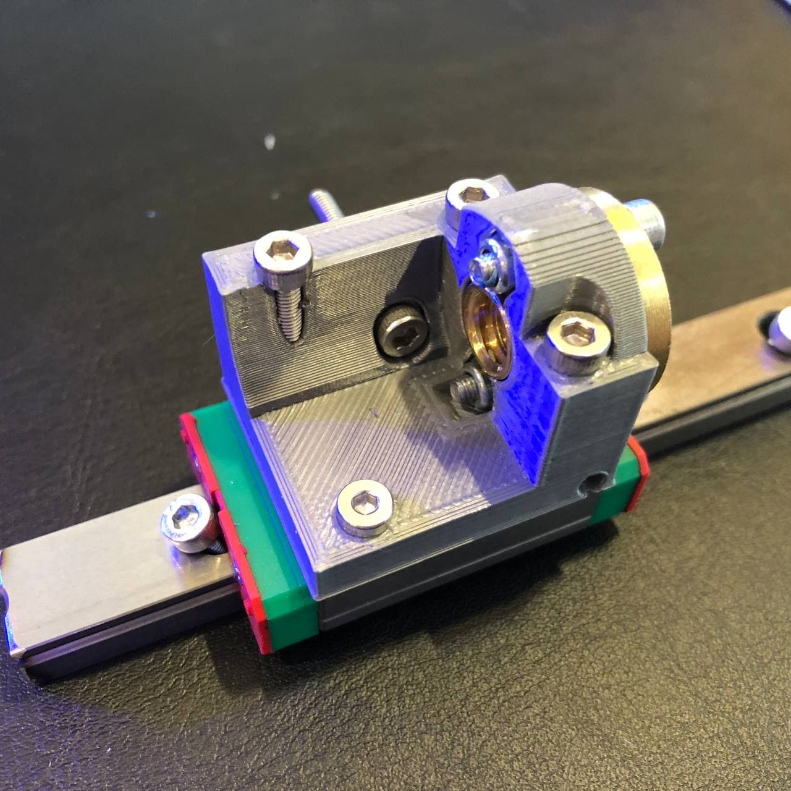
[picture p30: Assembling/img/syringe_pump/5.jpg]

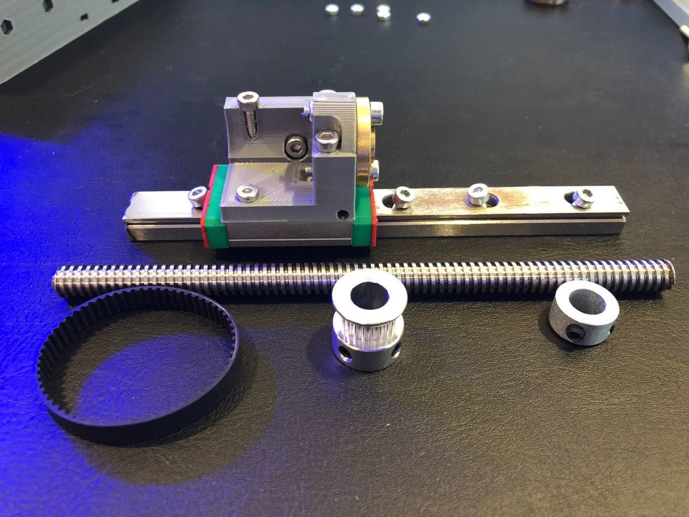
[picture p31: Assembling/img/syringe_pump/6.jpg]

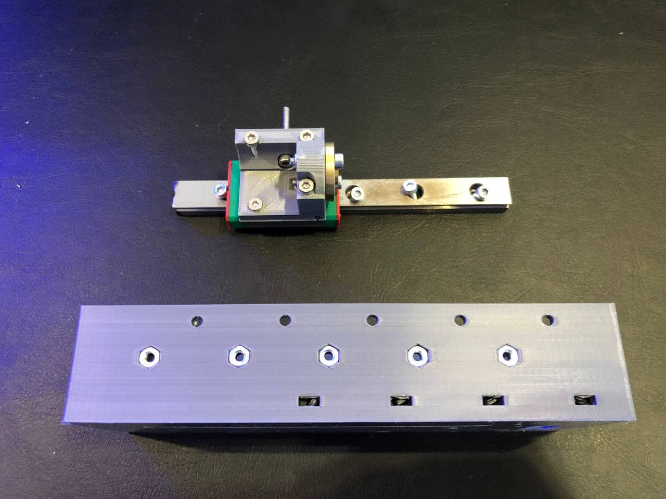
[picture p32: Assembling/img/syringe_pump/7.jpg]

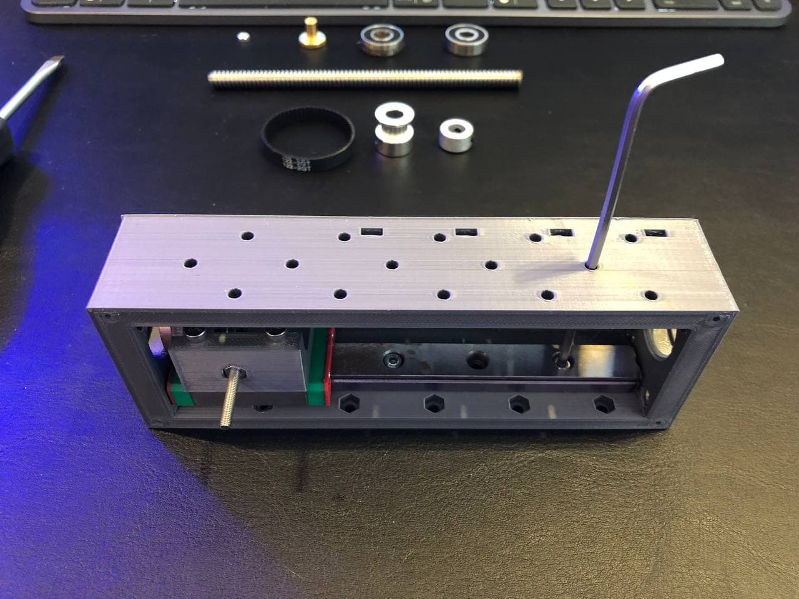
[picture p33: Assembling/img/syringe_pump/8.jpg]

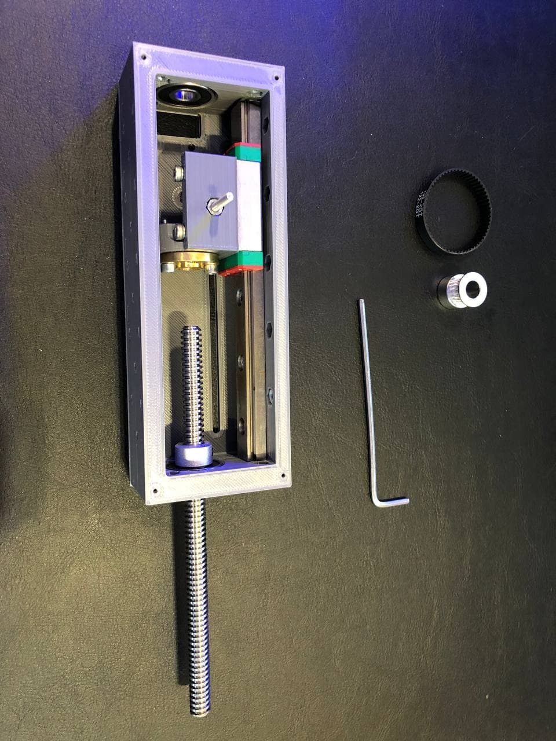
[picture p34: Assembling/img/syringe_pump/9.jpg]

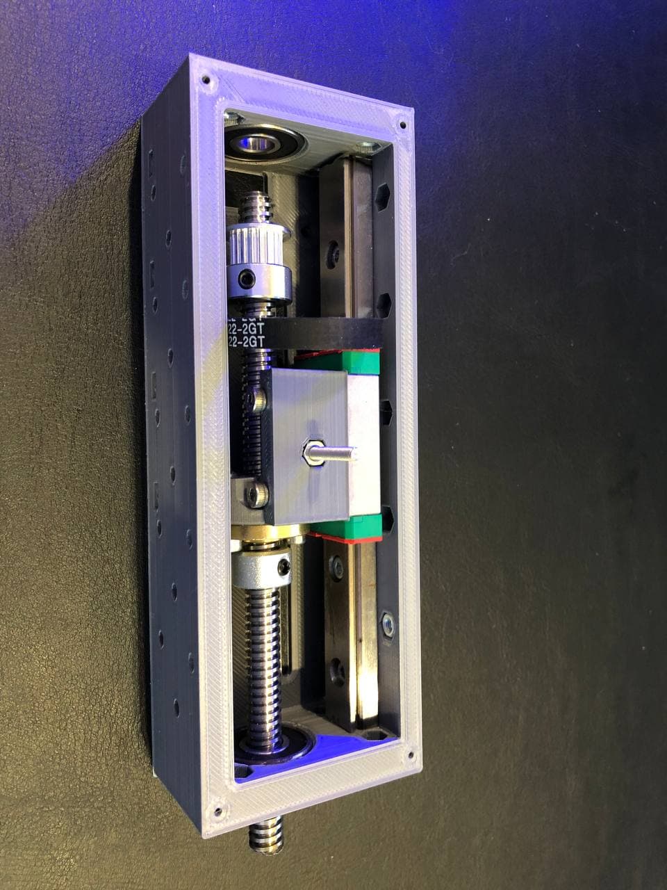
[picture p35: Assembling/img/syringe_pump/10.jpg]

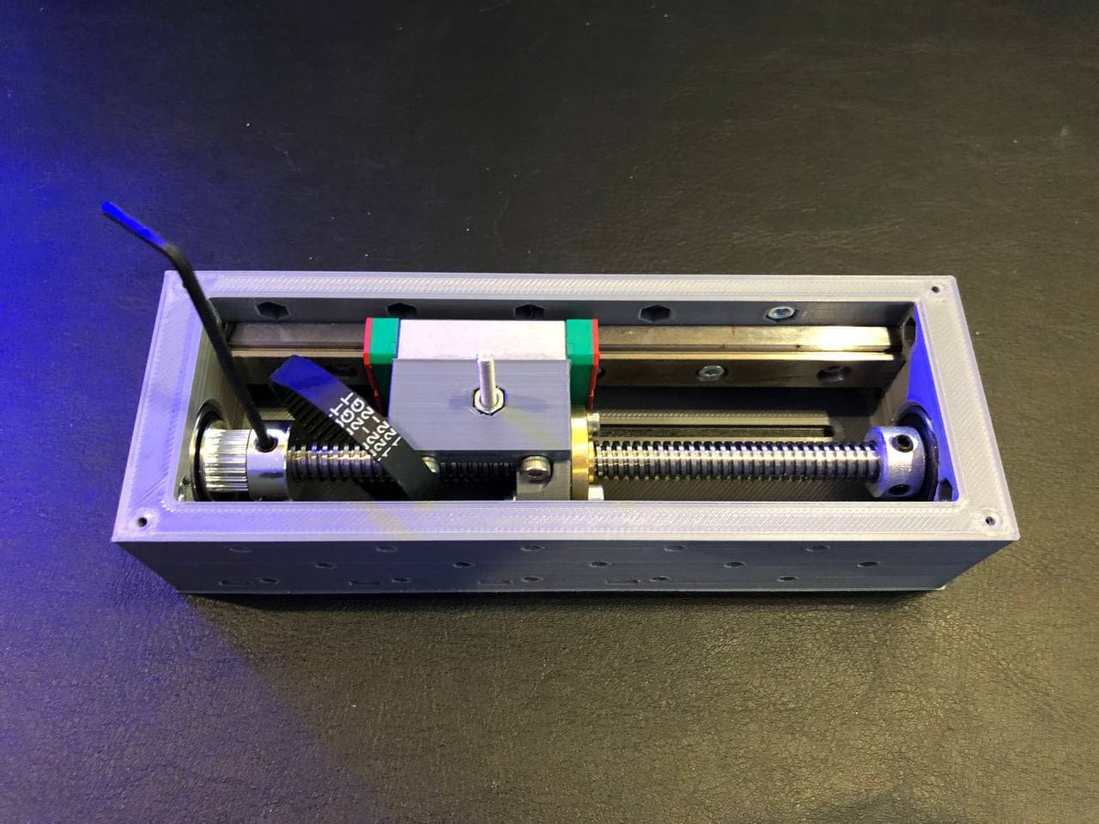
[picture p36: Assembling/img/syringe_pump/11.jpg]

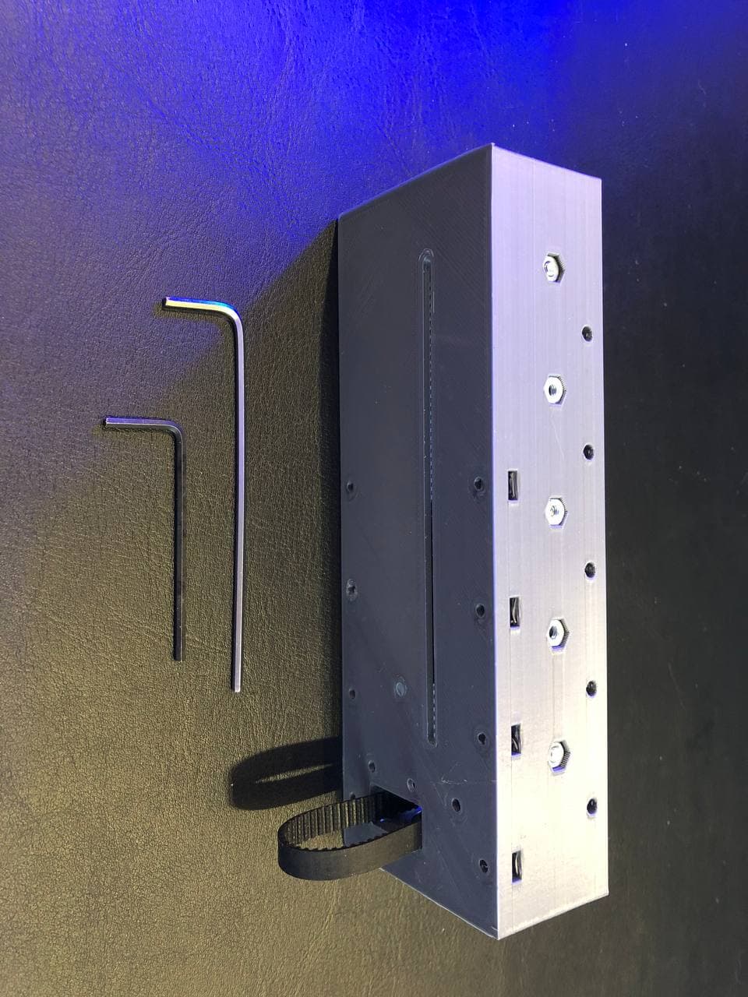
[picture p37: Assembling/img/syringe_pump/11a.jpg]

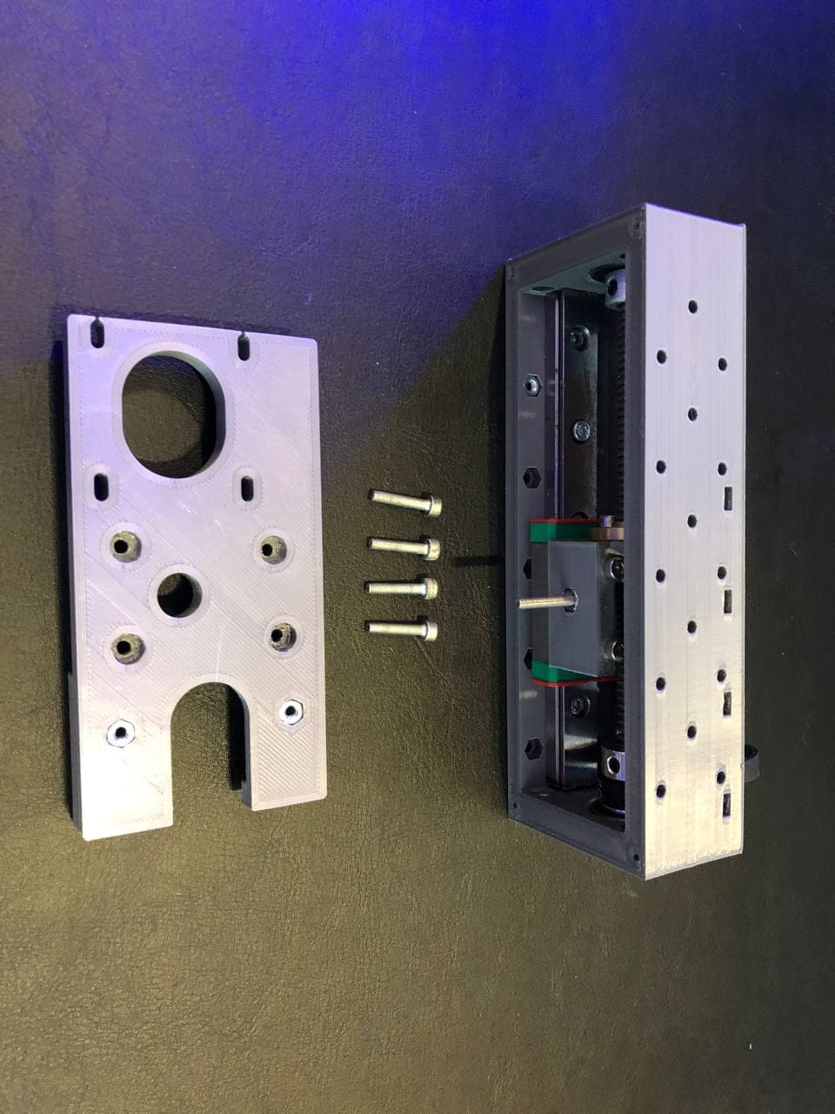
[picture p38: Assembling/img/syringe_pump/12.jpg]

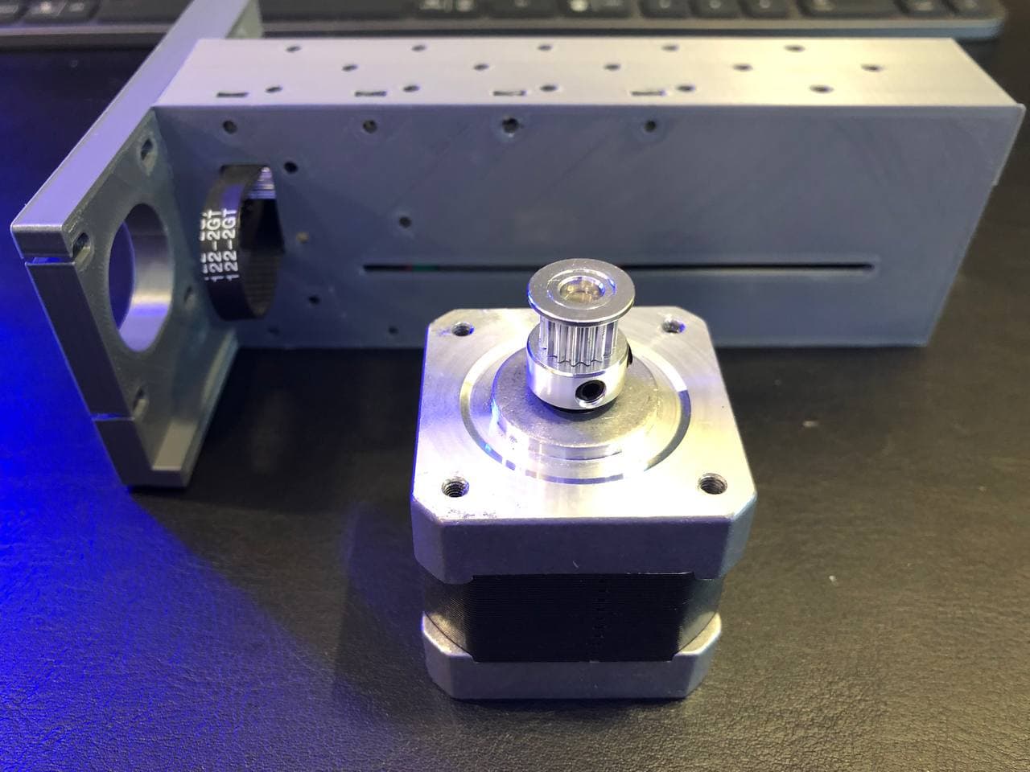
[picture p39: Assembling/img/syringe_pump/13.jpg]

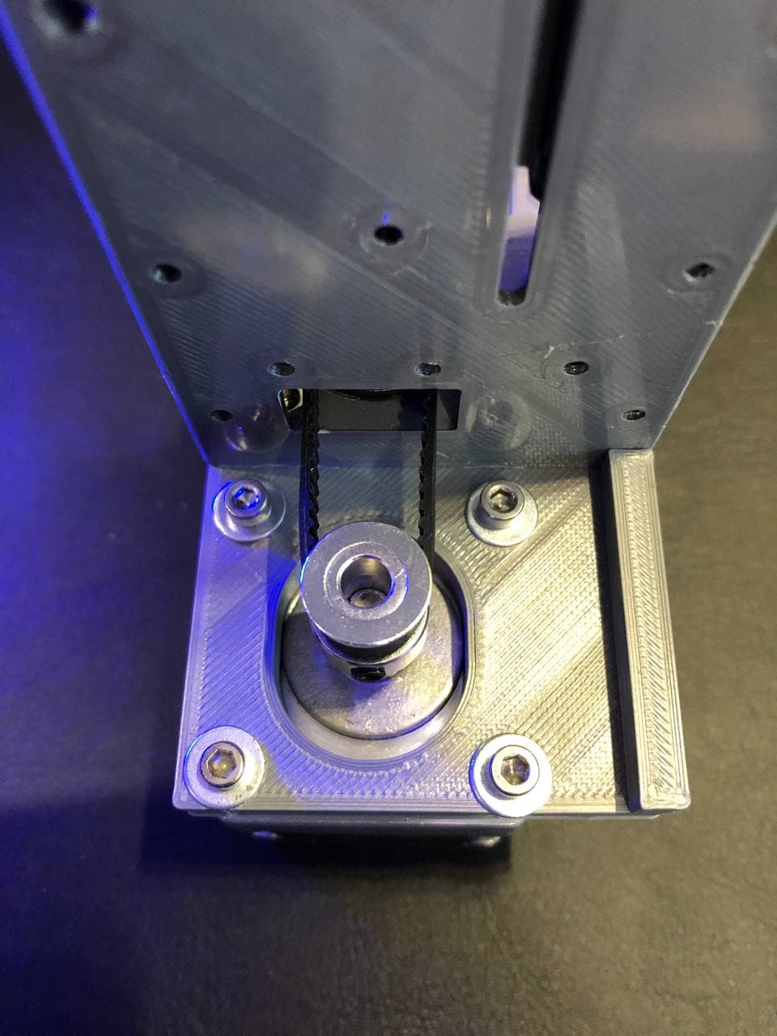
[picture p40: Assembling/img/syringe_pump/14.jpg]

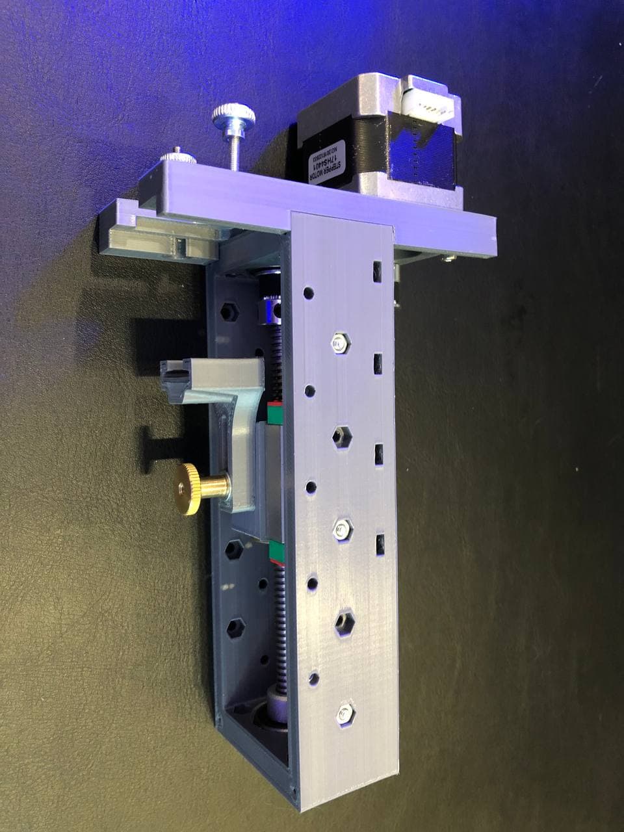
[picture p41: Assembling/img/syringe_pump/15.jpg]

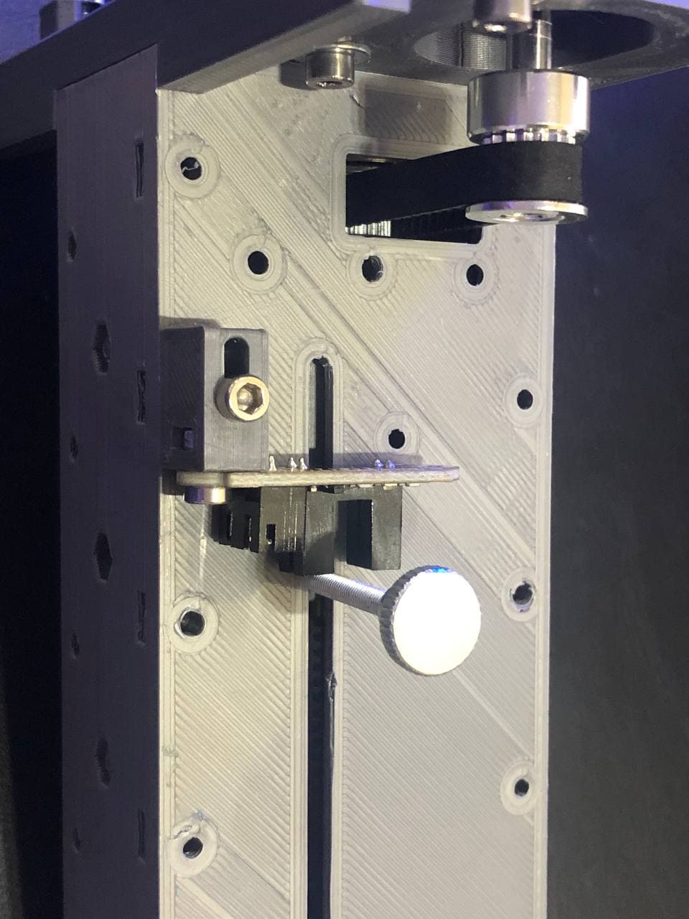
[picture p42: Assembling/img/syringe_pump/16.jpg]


>**Optical endstops and light.** The LERDGE endstops are optical: direct sunlight or a
>bright lamp falling into the slot blinds them, and homing stops working. Mount the pumps
>so the endstops are shaded, or put the station somewhere without direct sun.

## 2. Mounting pumps to the housing

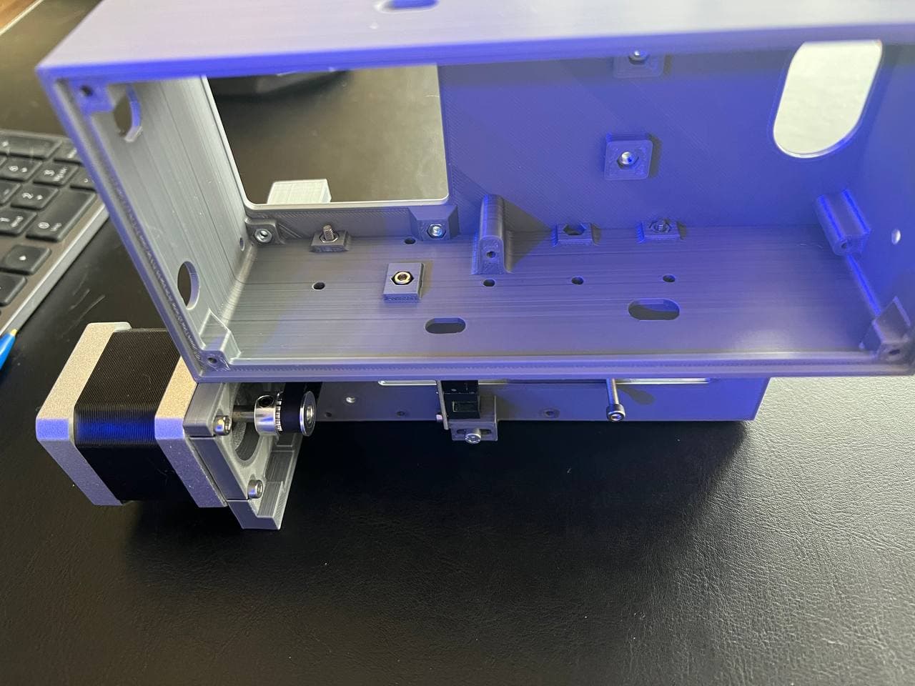
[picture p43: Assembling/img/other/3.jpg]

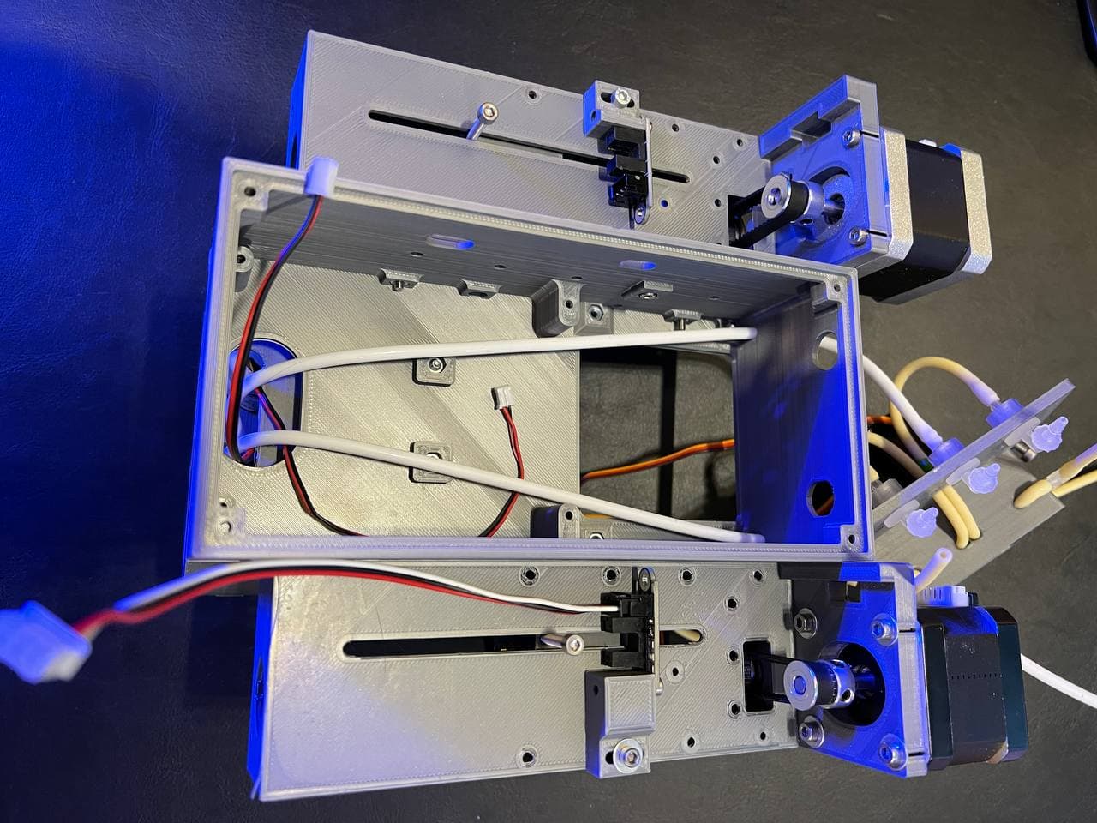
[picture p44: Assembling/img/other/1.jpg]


## 3. Mounting of emptying pump, magnetic stirrer, and guide plate

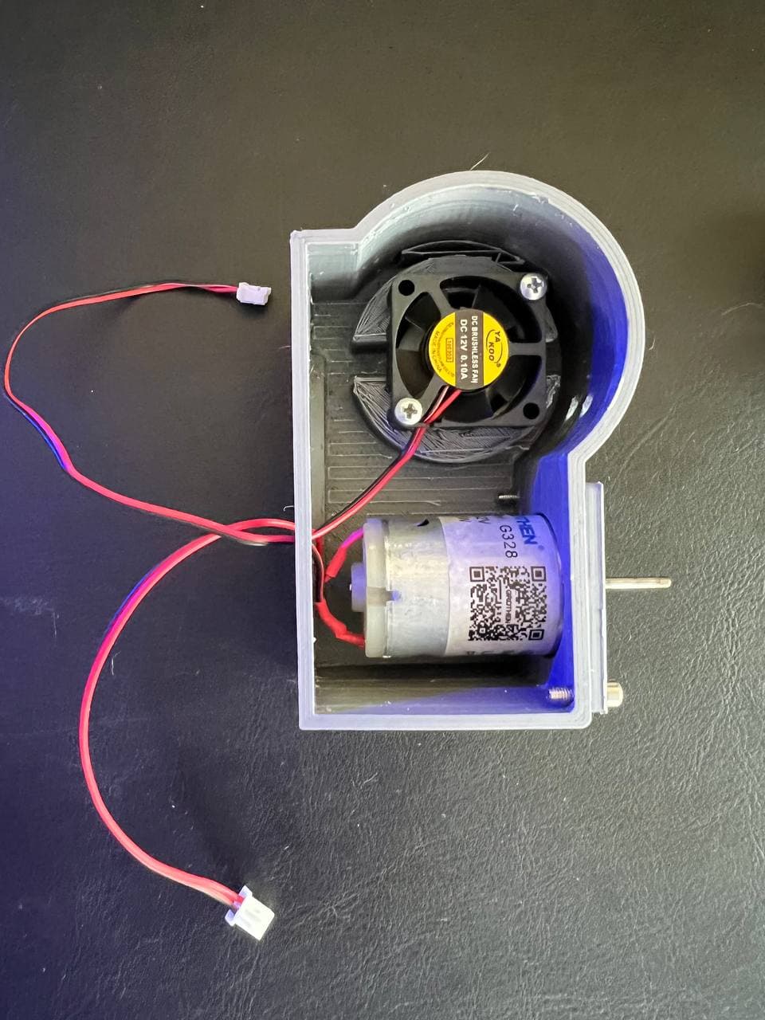
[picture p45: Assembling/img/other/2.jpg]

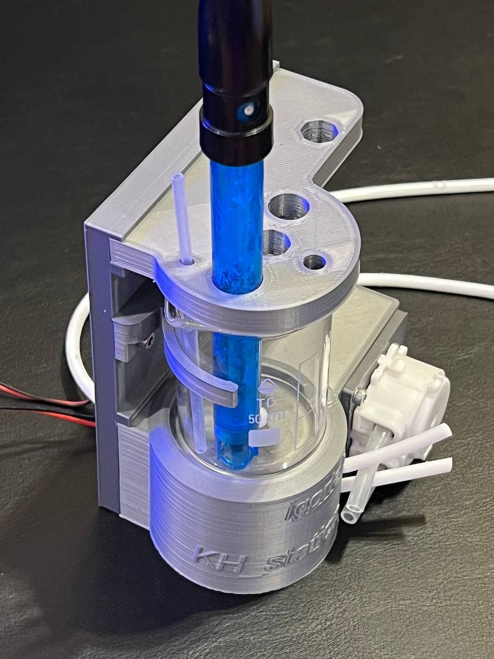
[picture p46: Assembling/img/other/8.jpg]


## 4. Assembling of servos and tubes for flow switcher

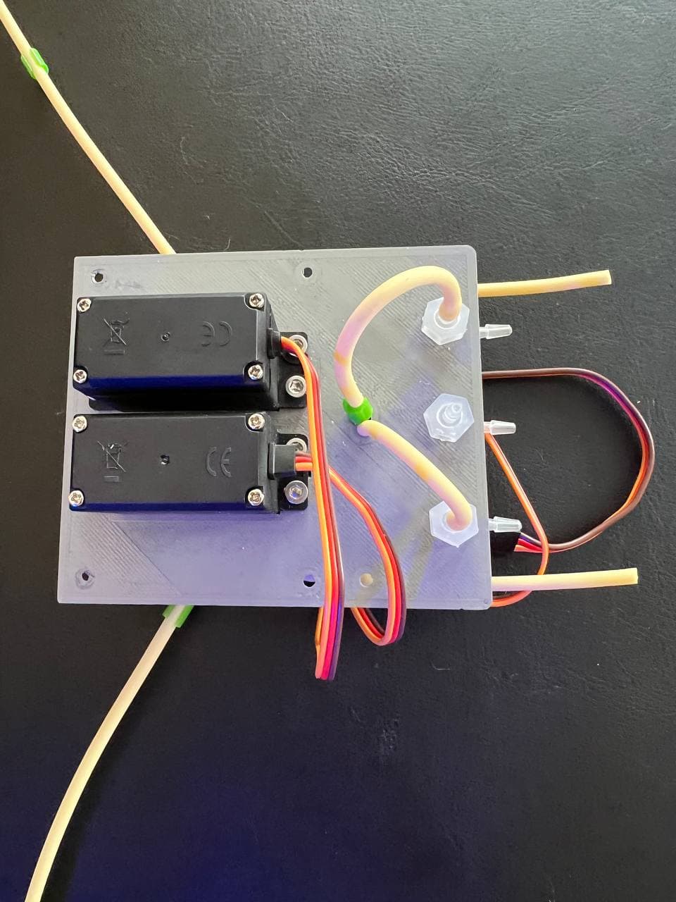
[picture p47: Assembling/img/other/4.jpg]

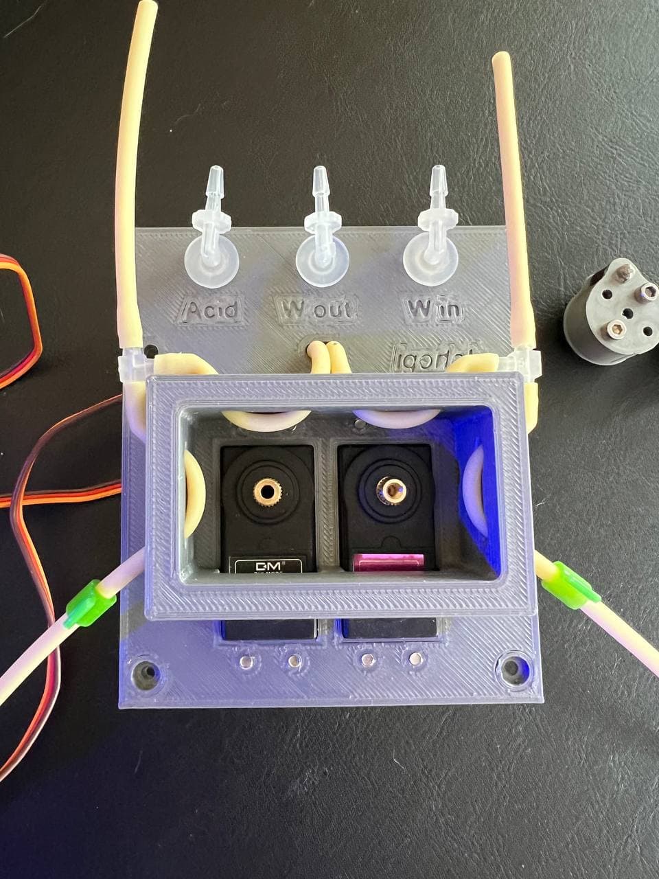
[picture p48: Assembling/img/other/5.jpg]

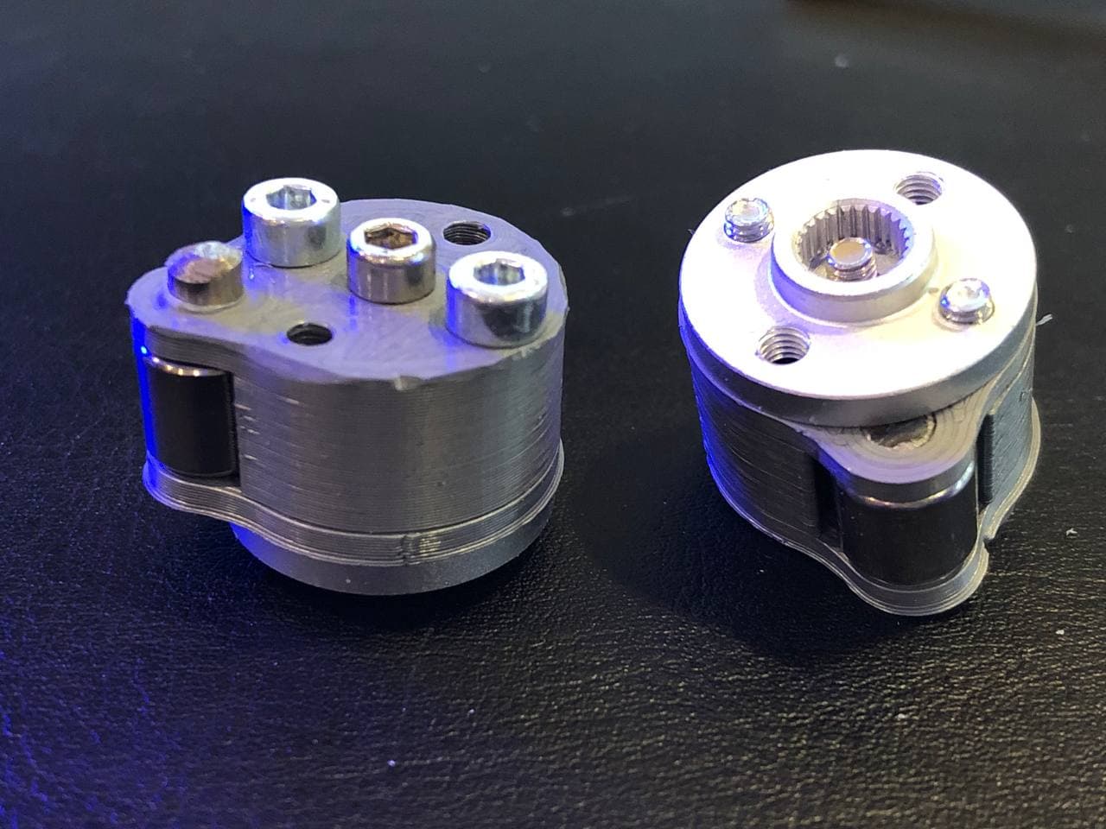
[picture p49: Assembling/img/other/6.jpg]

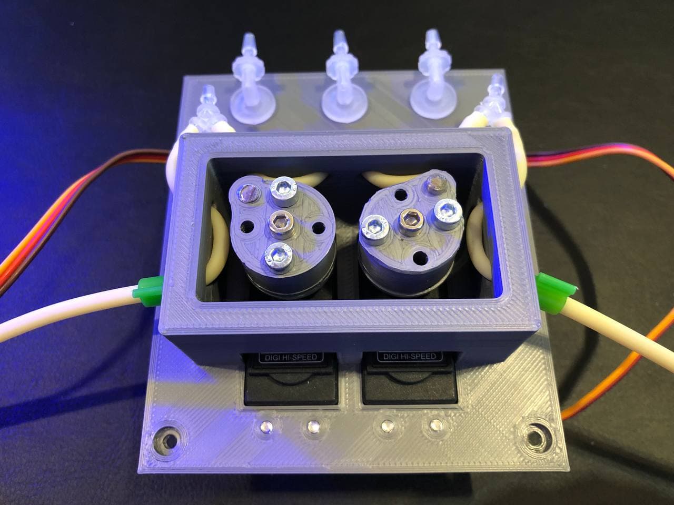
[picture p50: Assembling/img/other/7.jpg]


## 5. PCB

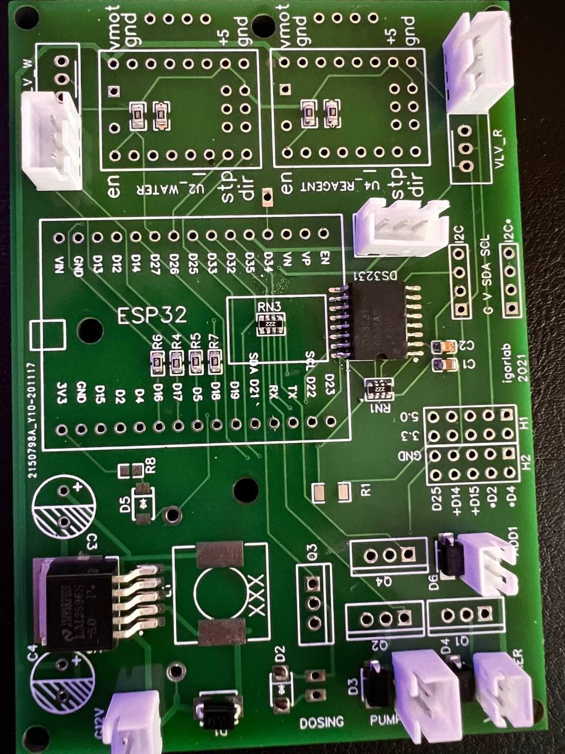
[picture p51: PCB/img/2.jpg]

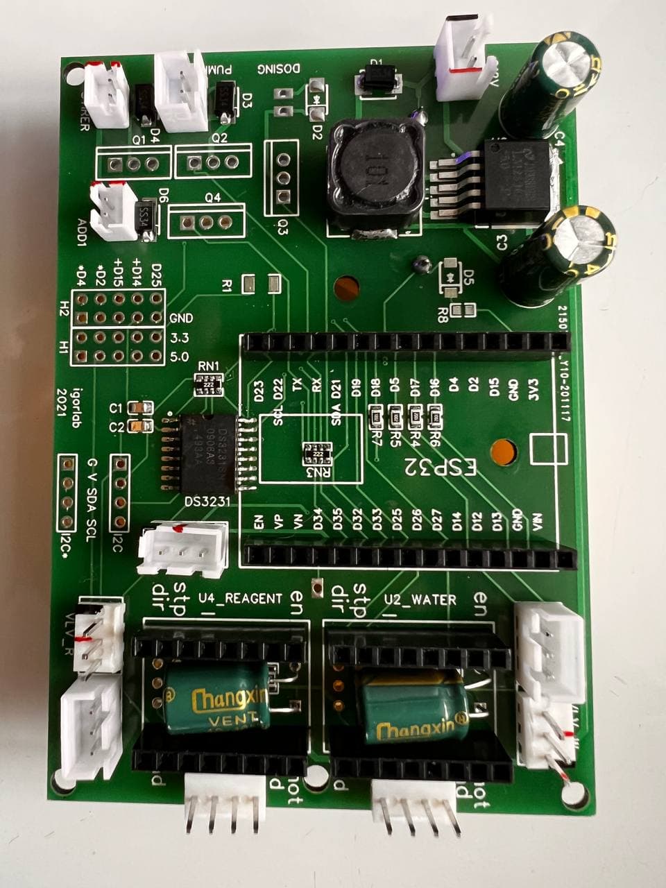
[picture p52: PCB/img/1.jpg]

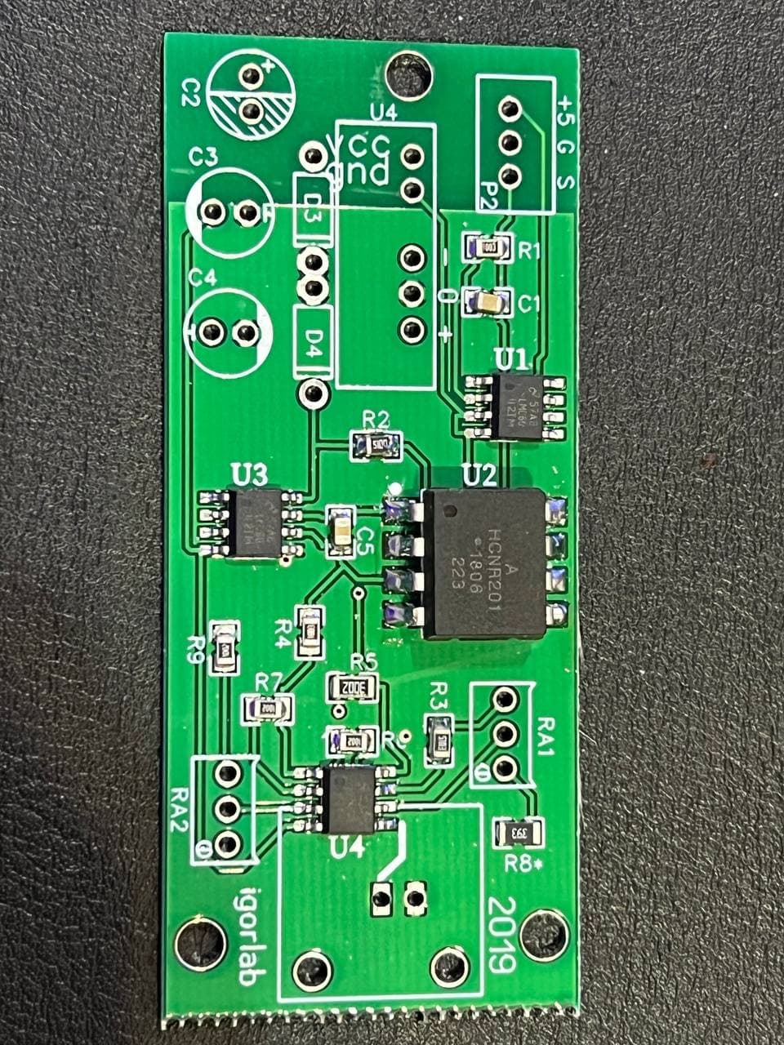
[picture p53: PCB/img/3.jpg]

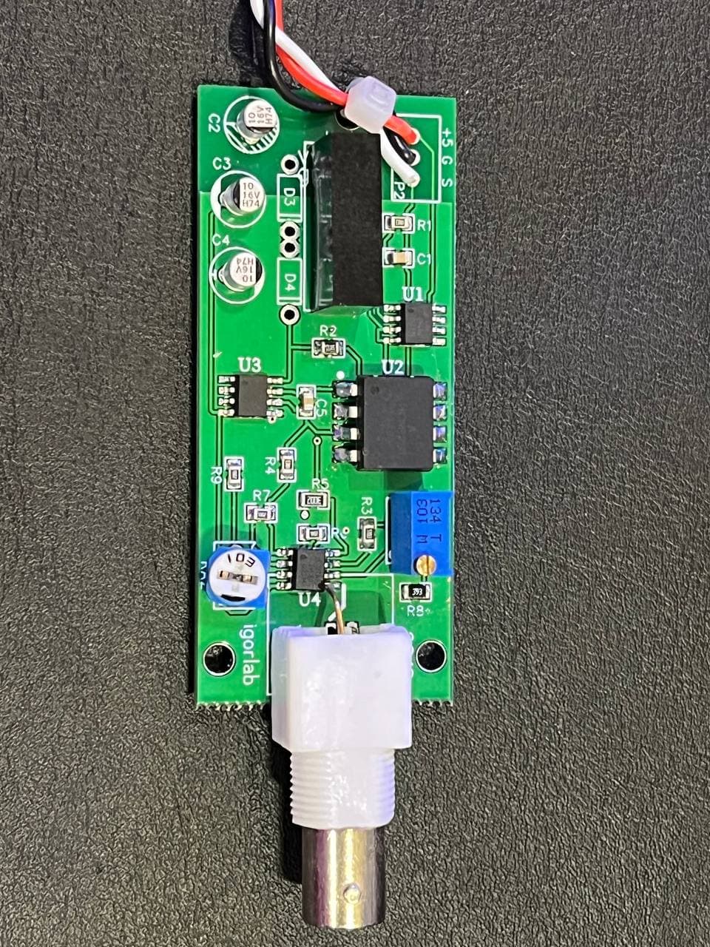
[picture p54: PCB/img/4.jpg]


## 3. Result should be like this

All parts
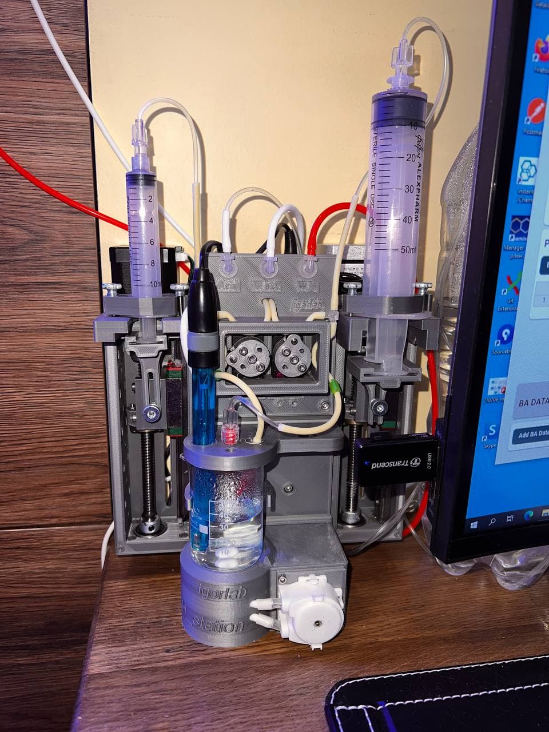
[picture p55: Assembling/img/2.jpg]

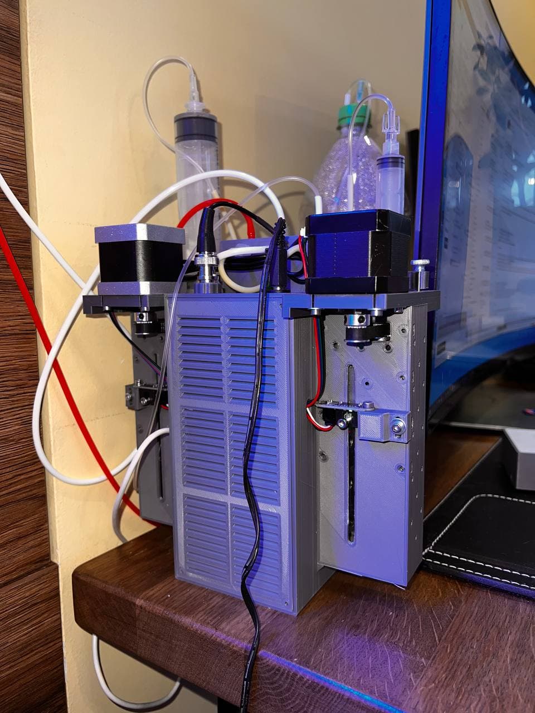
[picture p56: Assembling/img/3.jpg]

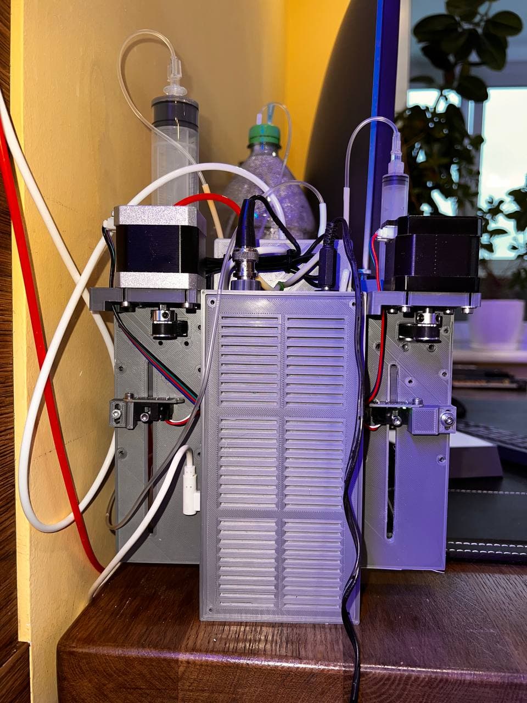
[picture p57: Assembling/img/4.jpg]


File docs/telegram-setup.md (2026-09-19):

# Setting up Telegram

The station talks to you through a Telegram bot of your own. Before you set it up you
need two things from Telegram:

1. a **bot token** — the bot's key, which the station uses to send and receive messages
2. your **Telegram ID** — a number that tells the station who it should listen to

It takes about five minutes, and you only do it once.

---

## 1. Create the bot

1. In Telegram, open [@BotFather](https://t.me/BotFather) — Telegram's own bot for
   making bots (it has a blue check mark) — and press **Start**.
2. Send `/newbot`.
3. BotFather asks for a **name**. That is what shows up in your chat list, for example
   `My KH station`. Anything works, and you can change it later.
4. Then it asks for a **username**: 5–32 characters, Latin letters, digits and `_`, and
   it must end in `bot`, for example `reef_kh_station_bot`. It has to be unique across
   all of Telegram, so if it is taken, try another. It can't be changed later.
5. BotFather replies with a link to your new bot and, below "Use this token to access
   the HTTP API:", the token. It looks like this:

   ```
   1234567890:AAHdqTcvCH1vGWJxfSeofSAs0K5PALDsaw
   ```

   Copy all of it — the digits, the colon and everything after. That is your **bot
   token**.
6. Tap the link to your bot (`t.me/<your bot's username>`) and press **Start**. Don't
   skip this: Telegram doesn't let a bot write to anyone who hasn't written to it first,
   so until you press Start the station can't send you anything.

> **Keep the token to yourself.** Whoever has it can read and send your bot's messages.
> If it ever leaks — a screenshot, a public post — get a new one in BotFather:
> `/mybots` → your bot → **API Token** → **Revoke current token**, then give the new
> token to the station the same way as below. The old one stops working right away.

---

## 2. Find your Telegram ID

Your ID is a number like `123456789`. It is **not** your @username and not your phone
number. There are two ways to get it.

### The quick way

Open [@userinfobot](https://t.me/userinfobot) and press **Start**. It answers with a
few lines about you; the number next to **Id** is what you need.

It is a third-party bot, not part of Telegram. It sees what any bot sees when you
message it — your name, username and ID — and nothing more.

### Without a third-party bot

Your own bot can tell you, as long as the station isn't using it yet:

1. Send your new bot any message, e.g. `hi`. It won't answer — that's fine.
2. Open this address in a browser, with your token in place of `<TOKEN>`:

   ```
   https://api.telegram.org/bot<TOKEN>/getUpdates
   ```

   The word `bot` goes straight in front of the token, with nothing in between:
   `https://api.telegram.org/bot1234567890:AAHdq.../getUpdates`
3. The page is a wall of text. Press **Ctrl+F** (**Cmd+F** on a Mac), search for
   `"chat":{"id":`, and the number right after it is your ID:

   ```
   "chat":{"id":123456789,"first_name":"...","type":"private"}
   ```

If the page shows only `{"ok":true,"result":[]}`, send the bot another message and
reload. Once the station has the token it collects the bot's messages itself every few
seconds, and this page stays empty — use @userinfobot then.

---

## 3. Give both to the station

The first time, this has to be done on the station's setup page or over USB — the
bot doesn't know you yet, so it won't take commands from you in Telegram.

**On the setup page.** Open `http://kh-station.local/settings` (or
`http://<device-ip>/settings`, or the **station setup** link at the bottom of the
dashboard). In the **Telegram** box, paste the token into **Bot token** and your ID
into **Your chat ID**, and press **Save**. The page comes back with "Saved: Telegram bot
token, chat ID", and under each field shows what the station has stored now — the
token only by its last six characters. Empty fields are left as they are, so later you
can change one of them without retyping the other.

(Firmware older than 2.5.15 has a plainer page: the fields are **Telegram Bot token**
and **Telegram UserID**, the button is **Submit**, and it doesn't show what is stored.)

**Or over USB**, in a serial monitor at 115200 baud, one line at a time:

```
bottoken_1234567890:AAHdqTcvCH1vGWJxfSeofSAs0K5PALDsaw
settlgrmid_123456789
```

The station answers `New BOTtoken accepted (...)` with the token's length and last four
characters — it never prints the token back in full — and `Telegram ID = 123456789`.

**Check it works.** No restart is needed. Send your bot `lastkh`; the answer should come
within about ten seconds, with the station's buttons under the message field. From then
on you can do everything from the chat.

---

## If the bot stays silent

- **You didn't press Start in your bot.** Open it and press Start (or send any message).
- **The ID is wrong.** It must be digits only — no @username, no spaces. The station
  obeys exactly one chat, so with a wrong ID it answers nobody, and you can't fix it
  from Telegram. The setup page shows the ID the station has now, under the field —
  compare it with yours and enter it again if it differs.
- **The token is incomplete.** It must be the whole line from BotFather, digits before
  the colon included. The station only refuses one that is clearly too short (it replies
  `BOTtoken is wrong`), so a token that lost a few characters on the way can still be
  accepted. If in doubt, copy it from BotFather again and re-enter it.
- **The station isn't online.** Open `http://kh-station.local/` — if the dashboard
  doesn't load, sort out Wi-Fi first (see the main [README](../README.md)).

If somebody else finds your bot and writes to it, the station ignores them and sends
you a `Spammer: <their name> <their id>` message, so you'll know.

**Moving to another Telegram account?** From your current chat, send
`settlgrmid_<new id>`. From that moment the station listens only to the new account —
remember to press Start in the bot there too.

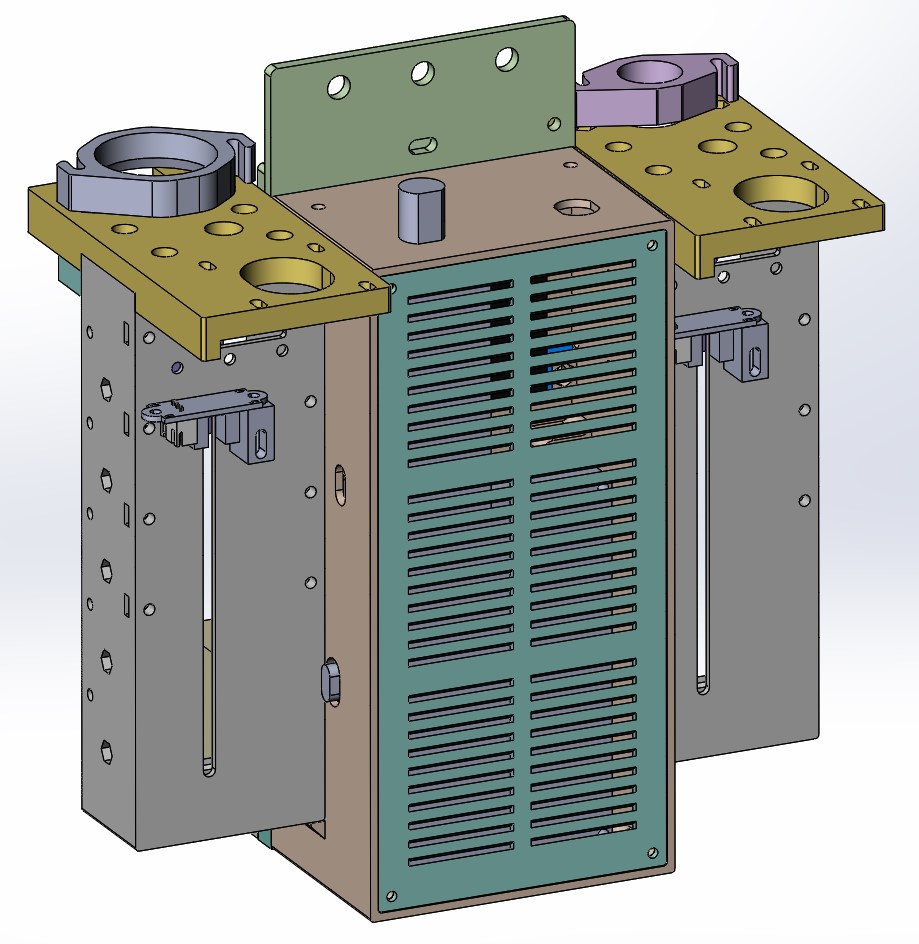
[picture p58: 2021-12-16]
Assembling/img/back1.jpg

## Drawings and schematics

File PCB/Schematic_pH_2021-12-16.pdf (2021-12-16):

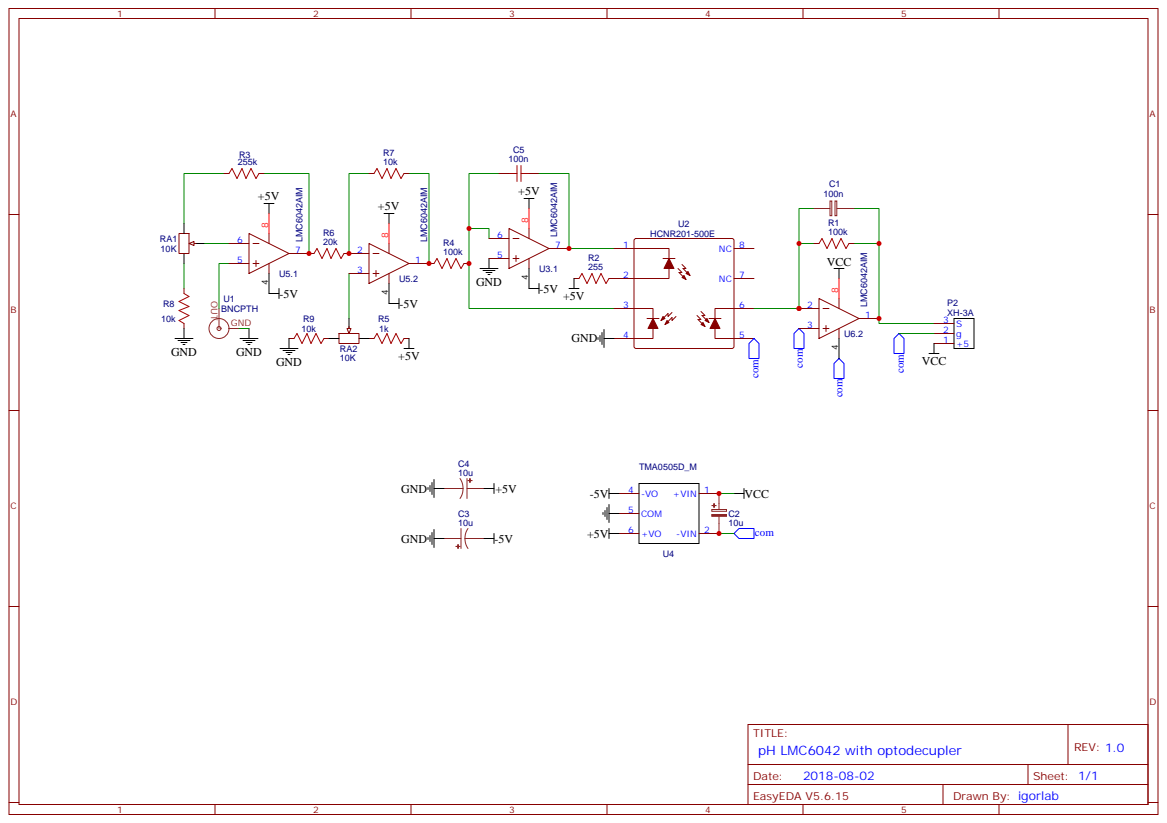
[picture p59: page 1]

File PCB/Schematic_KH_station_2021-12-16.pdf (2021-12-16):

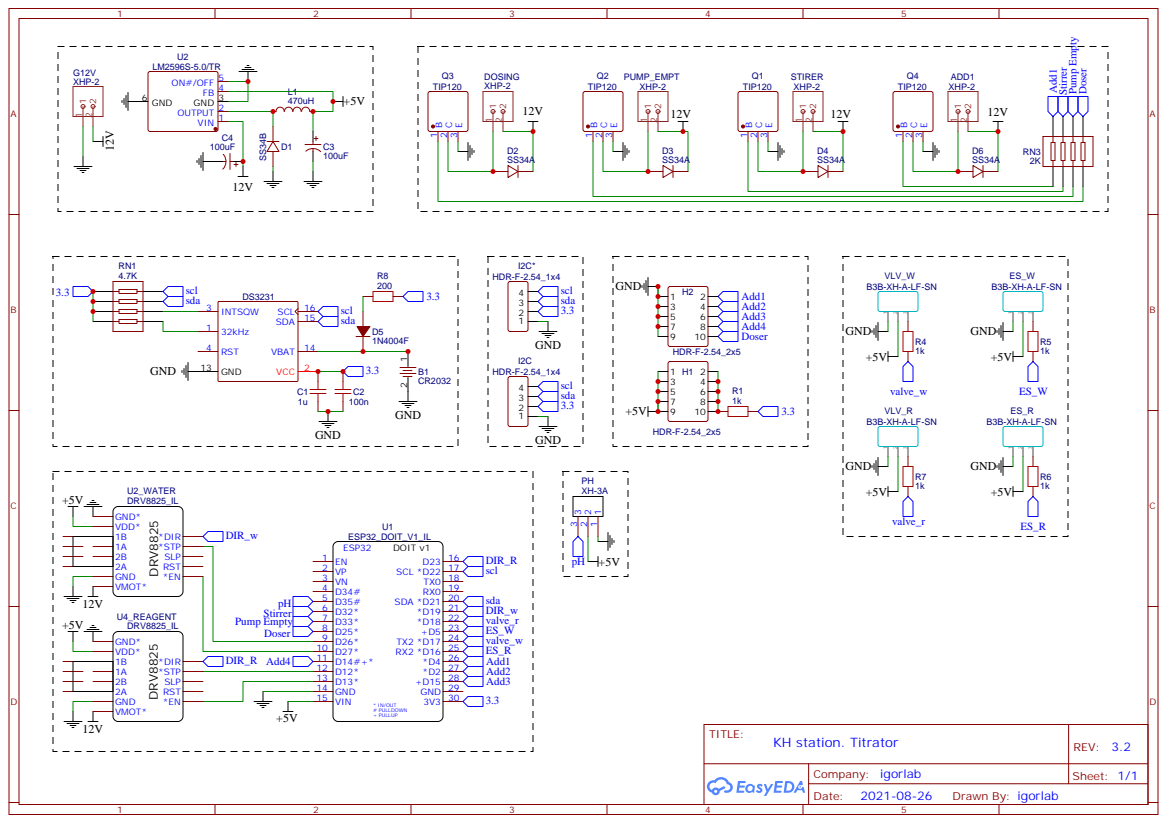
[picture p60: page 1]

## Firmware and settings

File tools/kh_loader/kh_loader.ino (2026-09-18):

/*
 * =============================================================================
 *  KH station - службовий завантажувач  /  service loader
 * =============================================================================
 *
 * -----------------------------------------------------------------------------
 *  НАЛАШТУЙТЕ ПЕРЕД ЗАЛИВКОЮ
 *  SET UP BEFORE YOU UPLOAD
 * -----------------------------------------------------------------------------
 *
 *  1) В Arduino IDE - три пункти, усі обовʼязкові:
 *     In the Arduino IDE - three settings, all required:
 *
 *    Tools > Board ................. ESP32 Dev Module
 *
 *    Tools > Partition Scheme ...... "Minimal SPIFFS (1.9MB APP with OTA/128KB SPIFFS)"
 *
 *        НЕ дефолтна. Прошивка ~1.6 МБ, а дефолтна схема дає лише 1.31 МБ на
 *        слот - завантаження пройшло б, а встановлення впало б у самому кінці.
 *        NOT the default. The firmware is ~1.6 MB and the default scheme gives
 *        only 1.31 MB per slot: the download would succeed, the install would
 *        fail at the very end.
 *
 *    Tools > Erase All Flash Before Sketch Upload ..... Disabled
 *
 *        !!! ЯКЩО ТУТ Enabled - ЗАЛИВКА СОТРЕ NVS, тобто саме те калібрування,
 *        заради збереження якого цей скетч і існує. Усе доведеться міряти знову.
 *        !!! IF THIS IS Enabled THE UPLOAD WIPES NVS - exactly the calibration
 *        this tool exists to preserve. Everything would have to be measured again.
 *
 *  2) У коді нижче, у блоці ЗАПОВНІТЬ / EDIT, впишіть:
 *     In the code below, in the ЗАПОВНІТЬ / EDIT block, fill in:
 *
 *        WIFI_SSID / WIFI_PASS - назва й пароль вашої Wi-Fi мережі.
 *        Можна лишити порожніми: тоді скетч візьме мережу, до якої станція
 *        вже підключалася сама.
 *        WIFI_SSID / WIFI_PASS - your Wi-Fi network's name and password.
 *        May be left empty: the sketch then uses the network the station
 *        itself was already connecting to.
 *
 *        FW_BIN_URL вже вказує на офіційну прошивку з цього репозиторію -
 *        міняйте лише якщо у вас власний форк.
 *        FW_BIN_URL already points at this repo's official firmware - change
 *        it only if you are running your own fork.
 *
 *  3) Натисніть Upload, відкрийте Serial Monitor на 115200, щоб бачити, що
 *     відбувається.
 *     Press Upload, open Serial Monitor at 115200 to watch it work.
 *
 * -----------------------------------------------------------------------------
 *  ЩО ЦЕ РОБИТЬ
 *  WHAT THIS DOES
 * -----------------------------------------------------------------------------
 *
 *    1. Читає з памʼяті плати (NVS) усі константи калібрування і друкує їх,
 *       щоб у вас був запис ДО того, як щось відбудеться.
 *    2. Переносить старі назви ключів на ті, які читає поточна прошивка.
 *    3. Підключається до Wi-Fi і встановлює прошивку через інтернет.
 *
 *    Калібрування зберігається. Помпи й pH-електрод перекалібровувати не треба.
 *
 *    1. Reads every calibration constant out of the board's NVS and prints it,
 *       so you have a record before anything happens.
 *    2. Migrates the old key names to the ones the current firmware reads.
 *    3. Connects to Wi-Fi and installs the current firmware over the air.
 *    Your calibration survives. No need to calibrate the pumps or probe again.
 *
 * -----------------------------------------------------------------------------
 *  ГОЛОВНЕ: ЩО ЦЕЙ СКЕТЧ НІКОЛИ НЕ РОБИТЬ
 *  THE IMPORTANT PART: WHAT THIS SKETCH NEVER DOES
 * -----------------------------------------------------------------------------
 *
 *    ВІН НІКОЛИ НЕ ПЕРЕЗАПИСУЄ ЗНАЧЕННЯ, ЯКЕ ВЖЕ Є.
 *    IT NEVER OVERWRITES A VALUE THAT ALREADY EXISTS.
 *
 *    Запис у памʼять відбувається РІВНО В ОДНОМУ ВИПАДКУ: коли старий ключ є,
 *    а нового ще немає. Тоді значення копіюється зі старого імені на нове.
 *    A write happens in EXACTLY ONE CASE: the old key exists and the new one
 *    does not. Then the value is copied from the old name to the new one.
 *
 *    Якщо обидва імені вже присутні - значення ЗВІРЯЮТЬСЯ і показуються вам.
 *    Не чіпається нічого, навіть якщо вони різні. Живим вважається НОВИЙ ключ,
 *    бо саме його читає прошивка; старий - це залишок минулої версії.
 *    If both names are present the values are COMPARED and shown to you.
 *    Nothing is touched, even when they differ. The NEW key is the live one -
 *    it is what the firmware reads; the old one is residue.
 *
 *    Скетч НЕ стирає NVS, НЕ форматує флеш, НЕ скидає налаштування.
 *    It does NOT erase NVS, does NOT format flash, does NOT reset anything.
 *
 *    Хочете спершу лише подивитися - поставте DRY_RUN 1 нижче. Тоді не буде
 *    записано жодного байта, а звірка й дамп відпрацюють повністю.
 *    To look first without writing anything, set DRY_RUN to 1 below. The dump
 *    and the comparison still run in full; not a single byte is written.
 * =============================================================================
 */

#include <WiFi.h>
#include <WiFiClientSecure.h>
#include <HTTPClient.h>
#include <Update.h>
#include <Preferences.h>
#include <esp_ota_ops.h>
#include <esp_wifi.h>

// ======================= ЗАПОВНІТЬ / EDIT ===================================

// Порожньо = мережа, збережена на платі (та, до якої підключалася станція).
// Empty = the network saved on the board (the one the station was using).
static const char* WIFI_SSID = "";      // ЗАПОВНІТЬ: назва вашої Wi-Fi мережі
static const char* WIFI_PASS = "";      // ЗАПОВНІТЬ: пароль від неї

// Офіційна прошивка з цього репозиторію - те саме джерело, що й автооновлення
// самої прошивки (include/OTA.h, URL_fw_Bin). Міняйте лише для власного форку.
// This repo's official firmware - the same source the firmware's own OTA updater
// uses (include/OTA.h, URL_fw_Bin). Change only if you run your own fork.
#define FW_BIN_URL "https://raw.githubusercontent.com/igorlab/KH_station/master/firmware/firmware.bin"

// ========================== ОПЦІЇ / OPTIONS =================================

// 1 = тільки подивитися: дамп і звірка відпрацюють, але В NVS НЕ БУДЕ ЗАПИСАНО
//     НІЧОГО, і прошивка не встановлюватиметься. Безпечно запускати будь-коли.
// 1 = look only: dump and comparison run, NOTHING IS WRITTEN to NVS and no
//     firmware is installed. Safe to run at any time.
#define DRY_RUN 0

// Показувати токен Telegram і ключ labaqua повністю, а не замаскованими.
// Show the Telegram token and labaqua key in full instead of masked.
#define SHOW_SECRETS 0

// Лишіть 0. Ставте 1 тільки якщо скетч не компілюється через відсутність
// набору кореневих сертифікатів - це вимикає перевірку сервера, з якого
// завантажується прошивка.
// Leave at 0. Set to 1 only if the sketch will not compile because your core
// has no certificate bundle - it disables verification of the firmware server.
#define USE_INSECURE_TLS 0

// ============================================================================

#if !USE_INSECURE_TLS
extern const uint8_t rootca_crt_bundle_start[] asm("_binary_x509_crt_bundle_start");
// core 3.x wants the length too, and treats size 0 as "do not verify".
extern const uint8_t rootca_crt_bundle_end[] asm("_binary_x509_crt_bundle_end");
#endif

// Прошивка тримає все у цьому просторі імен Preferences. Не змінюйте.
// The firmware keeps everything in this Preferences namespace. Do not change.
static const char* NVS_NAMESPACE = "Settings";

static Preferences prefs;

// Лічильник РЕАЛЬНИХ записів у NVS. Друкується в кінці.
// Counter of ACTUAL writes to NVS. Printed at the end.
static int  nvsWrites  = 0;
static int  mismatches = 0;
static int  untouched  = 0;

// ---------------------------------------------------------- таблиця ключів
// Preferences не вміє перелічувати ключі, тому всі вони перелічені тут явно.
// Тип має збігатися з тим, чим писала прошивка: getFloat() на int32 не працює.
// (putInt і putLong обидва кладуть int32, тому I32 покриває обидва.)

enum KType { K_STR, K_I32, K_U32, K_FLT, K_BOOL, K_BYTES };

struct KeyDef {
  const char* key;
  KType       type;
  bool        secret;
  const char* what;      // українською - це читає оператор
};

static const KeyDef KEYS[] = {
  // --- калібрування помп і електрода: найдорожче, міряне руками ---
  { "cal_r_step",     K_I32,  false, "помпа реагенту, кроків на r_volume" },
  { "cal_w_step",     K_I32,  false, "помпа води, кроків на w_volume" },
  { "cal_e_sec",      K_I32,  false, "помпа зливу, секунд на w_volume" },
  { "r_volume",       K_FLT,  false, "обʼєм шприца реагенту, мл" },
  { "w_volume",       K_FLT,  false, "аліквота води, мл" },
  { "pH1",            K_FLT,  false, "точка калібрування pH 1" },
  { "pH1_adc",        K_FLT,  false, "  її показ АЦП" },
  { "pH2",            K_FLT,  false, "точка калібрування pH 2" },
  { "pH2_adc",        K_FLT,  false, "  її показ АЦП" },
  { "valv_r_f",       K_I32,  false, "клапан реагенту, кут набору" },
  { "valv_r_i",       K_I32,  false, "клапан реагенту, кут подачі" },
  { "valv_w_f",       K_I32,  false, "клапан води, кут набору" },
  { "valv_w_i",       K_I32,  false, "клапан води, кут подачі" },

  // --- налаштування процесу ---
  { "KH_index",       K_FLT,  false, "коефіцієнт корекції KH" },
  { "maxDeviation",   K_FLT,  false, "макс. відхилення KH до перетитрування" },
  { "retitrHour",     K_I32,  false, "титрувати кожні N годин" },
  { "stirrerd",       K_I32,  false, "потужність мішалки (ШІМ)" },
  { "r_Allvolume",    K_FLT,  false, "запас реагенту, літрів" },

  // --- швидкості кроків ---
  { "step_hz",        K_I32,  false, "швидкість кроків, Гц (стара єдина)" },
  { "home_hz",        K_I32,  false, "швидкість хомінгу, Гц" },
  { "fill_hz",        K_I32,  false, "швидкість набору, Гц" },
  { "dose_hz",        K_I32,  false, "швидкість дозування, Гц" },

  // --- фільтр pH ---
  { "ph_mea",         K_FLT,  false, "фільтр pH, похибка вимірювання" },
  { "ph_est",         K_FLT,  false, "фільтр pH, похибка оцінки" },
  { "ph_q",           K_FLT,  false, "фільтр pH, q" },
  { "phSimMode",      K_BOOL, false, "симулятор pH увімкнено" },

  // --- поточний стан ---
  { "lastkh",         K_FLT,  false, "останній прийнятий KH" },
  { "r_usd_vol",      K_FLT,  false, "витрачено реагенту, мл" },
  { "countTitr",      K_U32,  false, "титрувань, усього" },
  { "countTitrReset", K_U32,  false, "титрувань, скидний лічильник" },
  { "version",        K_STR,  false, "версія прошивки, що стартувала востаннє" },

  // --- ідентичність ---
  { "CHAT_ID",        K_STR,  false, "Telegram chat id" },
  { "Es_BOTtoken",    K_STR,  true,  "токен Telegram-бота" },
  { "u_key",          K_STR,  true,  "ключ labaqua" },
  { "dosserIP",       K_STR,  false, "IP дозатора" },
  { "macAddr",        K_BYTES,false, "MAC для ESP-NOW" },

  // --- застарілі, лишені щоб дамп був повним ---
  { "vol_w_ml",       K_FLT,  false, "СТАРЕ: аліквота води" },
  { "vol_r_ml",       K_FLT,  false, "СТАРЕ: обʼєм реагенту" },
  { "state.lastkh",   K_FLT,  false, "СТАРЕ: останній KH" },
  { "state.r_usd_vol",K_FLT,  false, "СТАРЕ: витрачено реагенту" },
  { "state.countTitr",K_U32,  false, "СТАРЕ: лічильник титрувань" },
  { "ssid1",          K_STR,  false, "СТАРЕ: назва Wi-Fi" },
  { "pswrd1",         K_STR,  true,  "СТАРЕ: пароль Wi-Fi" },
};
static const size_t KEY_COUNT = sizeof(KEYS) / sizeof(KEYS[0]);

// ------------------------------------------------------- карта перенесення
// Стара назва -> назва, яку читає поточна прошивка.
//
// Копіюється ТІЛЬКИ тоді, коли нового ключа НЕМАЄ. Якщо є обидва - значення
// звіряються і друкуються, не змінюється нічого.

struct Migration {
  const char* oldKey;
  const char* newKey;
  KType       type;
};

static const Migration MIGRATIONS[] = {
  { "vol_w_ml",        "w_volume",  K_FLT },
  { "vol_r_ml",        "r_volume",  K_FLT },
  { "state.lastkh",    "lastkh",    K_FLT },
  { "state.r_usd_vol", "r_usd_vol", K_FLT },
  { "state.countTitr", "countTitr", K_U32 },
};
static const size_t MIGRATION_COUNT = sizeof(MIGRATIONS) / sizeof(MIGRATIONS[0]);

// ------------------------------------------------------------------ помічники

static String maskSecret(const String& s) {
#if SHOW_SECRETS
  return s;
#else
  if (s.length() <= 8) return F("********");
  return s.substring(0, 4) + "..." + s.substring(s.length() - 4) +
         "  (" + String(s.length()) + " симв.)";
#endif
}

static String readAsText(const KeyDef& k) {
  if (!prefs.isKey(k.key)) return String("-");
  switch (k.type) {
    case K_STR: {
      String v = prefs.getString(k.key, "");
      if (v.length() == 0) return F("\"\"  (порожньо)");
      return k.secret ? maskSecret(v) : ("\"" + v + "\"");
    }
    case K_I32:  return String(prefs.getInt(k.key, 0));
    case K_U32:  return String(prefs.getULong(k.key, 0));
    case K_FLT:  return String(prefs.getFloat(k.key, 0.0f), 4);
    case K_BOOL: return prefs.getBool(k.key, false) ? F("так") : F("ні");
    case K_BYTES: {
      size_t n = prefs.getBytesLength(k.key);
      if (n == 0) return F("-");
      uint8_t buf[16];
      if (n > sizeof(buf)) n = sizeof(buf);
      prefs.getBytes(k.key, buf, n);
      String out;
      for (size_t i = 0; i < n; i++) {
        if (buf[i] < 16) out += '0';
        out += String(buf[i], HEX);
        if (i + 1 < n) out += ':';
      }
      return out;
    }
  }
  return F("?");
}

static void dumpAll() {
  Serial.println();
  Serial.println(F("============ ЩО ЗАРАЗ ЗБЕРЕЖЕНО НА ЦІЙ ПЛАТІ ================"));
  Serial.println(F("            WHAT IS STORED ON THIS BOARD"));
  Serial.println();
  Serial.println(F("  Збережіть цей текст. Це ваше калібрування."));
  Serial.println(F("  Save this text. It is your calibration."));
  Serial.println();
  Serial.printf("  %-16s %-24s %s\n", "КЛЮЧ", "ЗНАЧЕННЯ", "ЩО ЦЕ");
  Serial.println(F("  ------------------------------------------------------------"));

  int present = 0;
  for (size_t i = 0; i < KEY_COUNT; i++) {
    if (prefs.isKey(KEYS[i].key)) present++;
    Serial.printf("  %-16s %-24s %s\n",
                  KEYS[i].key, readAsText(KEYS[i]).c_str(), KEYS[i].what);
  }
  Serial.println(F("  ------------------------------------------------------------"));
  Serial.printf("  Присутньо %d ключів із %d відомих.\n", present, (int)KEY_COUNT);
  Serial.printf("  %d of %d known keys are present.\n", present, (int)KEY_COUNT);

  if (present == 0) {
    Serial.println();
    Serial.println(F("  ПАМʼЯТЬ ПОРОЖНЯ. Це або нова плата, або флеш був стертий."));
    Serial.println(F("  Прошивка стартує з вбудованими значеннями, і помпи та"));
    Serial.println(F("  pH-електрод доведеться калібрувати."));
    Serial.println(F("  NOTHING IS STORED - new board, or the flash was erased."));
  }
}

static void migrateOne(const Migration& m) {
  const bool hasOld = prefs.isKey(m.oldKey);
  const bool hasNew = prefs.isKey(m.newKey);

  // --- обох немає: робити нічого ---
  if (!hasOld && !hasNew) {
    Serial.printf("  %-16s -> %-14s  немає обох, пропуск / neither present\n",
                  m.oldKey, m.newKey);
    return;
  }

  // --- є тільки новий: плата вже на новій прошивці ---
  if (!hasOld && hasNew) {
    untouched++;
    Serial.printf("  %-16s -> %-14s  вже перенесено, НЕ ЧІПАЮ / already done\n",
                  m.oldKey, m.newKey);
    return;
  }

  // --- є тільки старий: ЄДИНИЙ випадок, коли відбувається запис ---
  if (hasOld && !hasNew) {
    String val;
    switch (m.type) {
      case K_FLT: val = String(prefs.getFloat(m.oldKey, 0.0f), 4); break;
      case K_U32: val = String((unsigned long)prefs.getULong(m.oldKey, 0)); break;
      case K_I32: val = String((long)prefs.getInt(m.oldKey, 0)); break;
      default:
        Serial.printf("  %-16s -> %-14s  тип не підтримано, пропуск\n", m.oldKey, m.newKey);
        return;
    }

#if DRY_RUN
    Serial.printf("  %-16s -> %-14s  [DRY_RUN] записав би %s\n",
                  m.oldKey, m.newKey, val.c_str());
    Serial.printf("  %-16s     %-14s  [DRY_RUN] would write %s\n", "", "", val.c_str());
    return;
#else
    switch (m.type) {
      case K_FLT: prefs.putFloat(m.newKey, prefs.getFloat(m.oldKey, 0.0f)); break;
      case K_U32: prefs.putULong(m.newKey, prefs.getULong(m.oldKey, 0));    break;
      case K_I32: prefs.putInt  (m.newKey, prefs.getInt  (m.oldKey, 0));    break;
      default: return;
    }
    nvsWrites++;
    Serial.printf("  %-16s -> %-14s  ПЕРЕНЕСЕНО %s  (новий ключ був порожній)\n",
                  m.oldKey, m.newKey, val.c_str());
    Serial.printf("  %-16s     %-14s  COPIED %s (new key was empty)\n", "", "", val.c_str());
    return;
#endif
  }

  // --- є обидва: ЗВІРЯЄМО, НЕ ПИШЕМО ---
  bool   same = false;
  String oldTxt, newTxt;
  switch (m.type) {
    case K_FLT: {
      const float a = prefs.getFloat(m.oldKey, 0.0f);
      const float b = prefs.getFloat(m.newKey, 0.0f);
      same = fabsf(a - b) < 0.0001f;
      oldTxt = String(a, 4); newTxt = String(b, 4);
      break;
    }
    case K_U32: {
      const uint32_t a = prefs.getULong(m.oldKey, 0);
      const uint32_t b = prefs.getULong(m.newKey, 0);
      same = (a == b);
      oldTxt = String((unsigned long)a); newTxt = String((unsigned long)b);
      break;
    }
    case K_I32: {
      const int32_t a = prefs.getInt(m.oldKey, 0);
      const int32_t b = prefs.getInt(m.newKey, 0);
      same = (a == b);
      oldTxt = String((long)a); newTxt = String((long)b);
      break;
    }
    default:
      Serial.printf("  %-16s -> %-14s  тип не підтримано, пропуск\n", m.oldKey, m.newKey);
      return;
  }

  untouched++;

  if (same) {
    Serial.printf("  %-16s -> %-14s  є обидва, ЗБІГАЮТЬСЯ (%s), НЕ ЧІПАЮ\n",
                  m.oldKey, m.newKey, newTxt.c_str());
    Serial.printf("  %-16s     %-14s  both present, identical, untouched\n", "", "");
  } else {
    mismatches++;
    Serial.println();
    Serial.printf("  %-16s -> %-14s  ** ЗНАЧЕННЯ РІЗНІ / VALUES DIFFER **\n",
                  m.oldKey, m.newKey);
    Serial.printf("      старий  %-14s = %s\n", m.oldKey, oldTxt.c_str());
    Serial.printf("      новий   %-14s = %s   <-- прошивка читає САМЕ ЦЕЙ\n",
                  m.newKey, newTxt.c_str());
    Serial.println(F("      НІЧОГО НЕ ЗМІНЕНО. Новий ключ - живий, старий - залишок"));
    Serial.println(F("      попередньої версії. Рішення за вами, скетч не втручається."));
    Serial.println(F("      NOTHING CHANGED. The new key is live, the old is residue."));
    Serial.println();
  }
}

static void migrateAll() {
  Serial.println();
  Serial.println(F("================= ПЕРЕНЕСЕННЯ КЛЮЧІВ ========================"));
  Serial.println(F("                 KEY MIGRATION"));
  Serial.println();
  Serial.println(F("  Запис відбувається ЛИШЕ там, де старий ключ є, а нового немає."));
  Serial.println(F("  Скрізь, де нове значення вже існує, воно лишається як є."));
  Serial.println(F("  A write happens ONLY where the old key exists and the new"));
  Serial.println(F("  one does not. Existing new values are always left alone."));
#if DRY_RUN
  Serial.println();
  Serial.println(F("  >>> DRY_RUN = 1 : НЕ БУДЕ ЗАПИСАНО ЖОДНОГО БАЙТА <<<"));
  Serial.println(F("  >>> DRY_RUN = 1 : NOT A SINGLE BYTE WILL BE WRITTEN <<<"));
#endif
  Serial.println();

  for (size_t i = 0; i < MIGRATION_COUNT; i++) migrateOne(MIGRATIONS[i]);

  Serial.println(F("  ------------------------------------------------------------"));
  Serial.printf("  ЗАПИСАНО В ПАМʼЯТЬ: %d значень\n", nvsWrites);
  Serial.printf("  WRITTEN TO NVS:     %d values\n", nvsWrites);
  Serial.printf("  Залишено недоторканими: %d   Розбіжностей: %d\n", untouched, mismatches);
  Serial.printf("  Left untouched: %d   Differences found: %d\n", untouched, mismatches);

  if (nvsWrites == 0) {
    Serial.println(F("  Памʼять не змінювалася взагалі."));
    Serial.println(F("  Nothing in memory was modified at all."));
  }
  if (mismatches > 0) {
    Serial.println();
    Serial.println(F("  УВАГА: знайдено розбіжності (вище). Нічого не перезаписано -"));
    Serial.println(F("  прошивка працюватиме зі значеннями під НОВИМИ ключами."));
    Serial.println(F("  NOTE: differences found above. Nothing was overwritten; the"));
    Serial.println(F("  firmware will use the values under the NEW keys."));
  }
}
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
void loop() {
  delay(1000);
}

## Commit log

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2021-12-16 new stl
    [empty_pump_mount.STL, flow_switcher_body.STL, tap_rotor_base_v2.STL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]
2021-12-16 add PCB
    [BOM_KH_station_2021-12-16.csv]
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2021-12-17 update the motor_mount_plate
    [motor_mount_plate.STL, motor_mount_plate_50ml.STL]
2021-12-20 time loop fix
    [base_stirrer_empty.STL, pH_tube_holder.STL]
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2026-09-13 Document the station properly, and ship the service loader
    The README had the provisioning steps and the pump calibration and nothing
    else - no description of what the machine actually does, no command reference,
    no mention of the web dashboard, and nothing about the thing most likely to
    bite someone: updating a station that has been running since 2022.
    Now it covers the titration itself and the KH formula, the pin map, why the
    three step rates differ, provisioning, both calibrations, the dashboard, every
    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
2026-09-13 Release 2.4.0
    Replaces a binary from September 2022. 1.59 MB against the 1.92 MB OTA slot.
    Built from Arduino core 3.3.11 / ESP-IDF 5.5.5 and verified on a station: a
    full titration returned KH 8.044 where core 2.0.17 returned 8.032 and the
    theoretical figure is 8.055, with homing, the step rates and NVS all carried
    across untouched.
    What changed since 2.2.16, which is what most stations are still running:
    - aborts instead of reporting KH 0.00 when the electrode is disconnected
    - a titration can be stopped from anywhere; both syringes return home
    - new dashboard: station diagram, live titration curve, streaming console
    - pH waiting is settle-based, so runs finish several times fas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
2026-09-13 Release 2.4.2 - fixes over-the-air updates
    2.4.0 and 2.4.1 could download a firmware and would then always reject it as a
    bad image, so a station that reached either could not update itself again.
    Arduino core 3's HTTPUpdate gates the download on peek() != 0xE9, and peek()
    returns -1 when no body byte has been buffered yet. Over TLS the first byte
    routinely has not arrived at that moment, so a valid image is refused with
    "Verify Bin Header Failed". Core 2 won that race, which is why updating INTO
    2.4.0 worked - the download was being done by the old firmware - and why the
    problem only shows on the next update.
    This release streams the image itself instead, which blocks for the data rather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
2026-09-14 README: plainer, friendlier tone for newcomers
    Same structure and facts (commands, pins, step rates, all checked against the
    current firmware source), rewritten to read less like an engineering audit and
    more like a guide for someone building this for the first time. Also fixes the
    partition-scheme label: Arduino IDE actually says "128KB SPIFFS", not "190KB".
2026-09-14 kh_loader: lead with setup, ship a working firmware URL by default
    Required Arduino IDE settings and the two lines to edit now come before the
    explanation of what the sketch does. FW_BIN_URL now defaults to this repo's
    own firmware.bin instead of the literal placeholder "PUT-THE-FIRMWARE-URL-HERE"
    - there is only one correct value for anyone running the stock firmware.
    Also fixed the partition-scheme label: Arduino IDE actually says
    "...128KB SPIFFS", not "190KB".
    [kh_loader.ino]
2026-09-18 Release 2.5.0 - valve and pump calibration UI, mDNS
    Dashboard adds a Valves card mirroring the Pumps card's existing calibration
    flow: pick Fill or Inject, try an angle, check the real valve against a drawn
    target, save once it matches - the same rrvalve_/wwvalve_ and
    rrvalvesetfill_/rrvalvesetinject_ commands (and the ww equivalents) the
    Telegram flow already used, just without typing them by hand.
    The target picture is deliberately honest about what it can't know: a servo
    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
2026-09-18 Release 2.5.1 - fix the valve target arrow
    2.5.0 (previous commit) shipped the Valves card with its target arrow drawn
    as a plain dashed line with no arrowhead, underneath the red eccentric
    marker instead of on top of it. Both fixed: it's a real arrow again, and it
    always renders above the eccentric so nothing hides it.
2026-09-18 Release 2.5.3 - dashboard console keeps multi-line replies whole
    Also carries 2.5.2, which was never published on its own:
    - a bot token or LabAqua key sent through Telegram is kept exactly as typed
    (it used to be lower-cased, which broke it)
    - setstephz_ now survives a reboot
    - /settings leaves empty fields alone (it used to overwrite the chat ID with
    the literal "userID") and drops the Wi-Fi fields that never worked
    - the dashboard shows the firmware version and has a Check for update button
2026-09-18 Release 2.5.5 - backup Wi-Fi, version and signal in the dashboard header
    - Backup Wi-Fi (new in 2.5.4, which was never published on its own): if the
    main network is unreachable for a minute, the station joins a second one by
    itself and says so in Telegram. Set it on /settings or with
    wifibackup_<name>#<password>; wifibackup shows which network is in use,
    wifiswitch changes over by hand. At startup it tries the backup before
    falling back to the AutoConnectAP portal.
    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
2026-09-19 Release 2.5.14 - new dashboard header, back online by itself after a power cut
    Everything since 2.5.5:
    - 2.5.6: after a power cut the station no longer sits in the AutoConnectAP
    portal waiting for someone. It keeps titrating, looks for its network every
    minute and reconnects by itself; the portal still works for setup. Starting
    without internet no longer resets the clock to the year 2000.
    - 2.5.7-2.5.11: the dashboard fills in as soon as it opens,
    kh-station.local resolves at once, stirrer power and the KH doser IP can be
    set in the dashboard.
    - 2.5.12: the pH input is set up the way Arduino core 3 needs (readings and
    calibration unchanged).
    - 2.5.13: every start-up message says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
2026-09-19 Release 2.5.15 - real pH at every start, a setup page, the update message arrives
    - The station always starts on the real pH electrode; the simulator
    (phsim_1) only on request and only until the next restart.
    - New setup page at http://kh-station.local/settings, linked from the
    dashboard: Telegram bot token and chat ID, LabAqua token and backup Wi-Fi,
    showing what is set now.
    - The "KH station is UPDATED" message reaches Telegram again - since 2.5.4
    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
2026-09-19 Docs: Telegram guide follows the 2.5.15 setup page
    2.5.15 renamed the fields (Bot token, Your chat ID), the button is Save,
    and the page now shows what is stored. The old labels stay as a note for
    stations on older firmware.
2026-09-19 Release 2.5.24 - faster runs, a safer dashboard, HCl concentration as a setting
    - The water syringe now draws its next charge WHILE the reactor drains, in the
    titration and in washreactor alike. They are separate hardware - the drain is
    a pump on its own relay, and the water valve faces the reservoir for the whole
    fill - so about 40 seconds comes off every run.
    - Opening the dashboard during a titration can no longer corrupt the heap: the
    log dump on connect took the station's log without a lock while the titration
    task was appending to it.
    - The titration schedule is set in hours in steps of half an hour - 0.5, 1,
    1.5 ... 24 - instead of whole hours only. Existing settings carry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
2026-09-19 Release 2.5.31 - faster runs, a safer dashboard, HCl concentration as a setting
    Carries everything since 2.5.24.
    - The water syringe draws its next charge WHILE the reactor drains, in the
    titration and in washreactor alike: about 40 seconds off every run. They are
    separate hardware - the drain is a pump on its own relay, and the water valve
    faces the reservoir for the whole fill.
    - Opening the dashboard during a titration can no longer corrupt memory: the log
    dump sent on connect read the station's log without a lock while the titration
    was writing to it.
    - The schedule is set in hours in steps of half an hour - 0.5, 1, 1.5 ... 24 -
    instead of whole hours only. Existing settings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
2026-09-20 Release 2.5.43
    - more accurate reagent used-volume; steadier retitration
    - more reliable Telegram commands/confirmations; safer pH calibration
    - the schedule now needs a working RTC (and warns at boot if it is missing)
    - safer firmware updates; the dashboard is served gzip-compressed (~44 KB smaller)
    Previous published: 2.5.37.
2026-09-24 Release 2.5.52
    Supersedes 2.5.43. Run on the station and verified with a complete titration
    (KH 8.09 in 4:04) before publishing.
    STOP really stops. It used to be handled below the same lock that the command
    it was stopping already held, so during a long job - rrtest_20 is about half
    an hour - the dashboard STOP button did nothing at all, from any source. It is
    handled before the lock now, and in the web handler directly. A STOP pressed
    on an idle station also used to leave the machine armed to abort, so the next
    pump command failed for no visible reason; that is cleared now.
    Endstops are no longer believed on a single reading. A reading must hold for
    3 ms, and a loaded syringe that claims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
2026-09-25 Release 2.5.53
    Small step on top of 2.5.52, and it changes nothing until you ask it to.
    Quiet hours. Tell the station when NOT to titrate:
    quiet_22:00-08:00 quiet_off
    The window may cross midnight. Only the SCHEDULE is muted - you can still
    start a run by hand, a run already under way finishes, and a retitration
    still gets to check a result it has already started on.
    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
2026-09-25 Release 2.5.54
    An update now tells you how far it has got. While the image downloads the
    dashboard console prints
    OTA 45% 723968 / 1608496 bytes
    every five percent, and a line at the end saying whether it worked. Until now
    the station went quiet for the whole download with nothing to watch.
    Nothing else changed. This will first be visible on the update AFTER this one,
    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
2026-09-25 Release 2.5.55
    Every foldable card on the dashboard now starts folded - Readings, pH
    electrode, Pumps, Valves and Settings - so the page opens short and the
    console is in view without scrolling. Open the ones you want; nothing else
    changed.
    This is also the first update whose download you can watch: the station is
    already running 2.5.54, so the console will print the percentage as it goes.
2026-09-25 Release 2.5.57
    Installing an update is one click now. A command the station prints in the
    dashboard console - /updatedevice after a version check, /stoptitr in a
    warning - is clickable, and an Install update button appears beside Check for
    update once there is actually something to install. Until now the only way in
    was to retype the command by hand.
    The download readout added in 2.5.54 no longer swallows its opening line, so
    it starts at 0 % rather than 5 %.
    Also in this release: every foldable card on the dashboard starts folded, so
    the page opens short with the console in view.
2026-09-25 Release 2.5.58
    Fixes the Install update button that 2.5.57 introduced and shipped greyed
    out. It was wired into the pH calibration group by mistake, so it only came
    alive while a pH read was running - which is never, when you are trying to
    install firmware.
    It is now always visible in Settings under Firmware, greyed until a check
    actually finds something, and live once it does.
    If you are on 2.5.57 you can still update the old ways: the Telegram menu, or
    typing updatedevice in the console.
2026-09-25 Release 2.5.59
    You can go back a version now, and it takes seconds.
    rollbackinfo what is in the other slot, and whether going back is possible
    rollback go back to it and restart
    The station keeps two copies of the firmware in flash and updates alternate
    between them, so the version you were running before the last update is still
    there. Rolling back is not a download - nothing is fetched, the network is not
    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
2026-09-26 Release 2.5.60
    The station diagram now shows the reagent bottle: how much is left in
    millilitres, the percentage, and the level itself falling as it is used. Its
    hose runs out through the cap and down to the syringe valve, alongside the
    line to the reactor - the way the plumbing actually goes.
    The stirrer moves on the diagram while it is running. The button under it
    tells the truth as well: it used to say "Start stirrer" for a whole titration,
    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
2026-09-26 README: show the dashboard
    A screenshot of the real thing, clickable for full size, and an animation of a
    whole run - rinse, sample, settle, then dosing with the curve filling in step
    by step to the result.
    The animation is generated from the dashboard's own SVG rather than drawn
    separately, so it cannot drift away from what the page actually looks like.
2026-09-26 docs: keep the optical endstops out of direct sunlight
    Found on a real station: sunlight falling into the optical endstops' slot
    blinded them and homing stopped working.
    Claude-Session: https://claude.ai/code/session_01V3usSFFuKfgyYYzJeh52JR
2026-09-26 Release 2.5.61
    Three buttons no longer ask "are you sure": Last log and Check for update,
    which only read something and change nothing, and the Go button on the valve
    cards, which you press over and over while dialling an angle in.
    Everything that doses, drains, homes, resets a counter or writes a setting
    still asks.
2026-09-26 Release 2.5.62
    Valves move smoothly instead of slamming; the reagent valve no longer swings FILL -> INJECT -> FILL for nothing each cycle; valvehold_0 releases the servos when the station is idle; endstop errors point at direct sunlight.
2026-09-26 Release 2.5.63
    valvehold now has a switch in dashboard Settings, under Motion. Built from the segmented toggle the Pumps card already uses, so the page gains no new kind of control.
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2026-09-27 README: overview and screenshots first, labelled drawings of the station
    Move the short description, the dashboard screenshot, the titration GIF and a
    photo of a built station to the top, and the repository layout down next to
    Building from source. Replace the two plain CAD renders with front and back
    views that name each part.
    Claude-Session: https://claude.ai/code/session_01DMXPEafCmPnDZDJr4S11tz
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2026-10-13 Firmware 2.5.95
    A station without a Telegram bot token no longer resets its calibration, schedule, quiet hours and reagent counter to factory on every restart (a regression since 2.5.42). Hardware unchanged.
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
